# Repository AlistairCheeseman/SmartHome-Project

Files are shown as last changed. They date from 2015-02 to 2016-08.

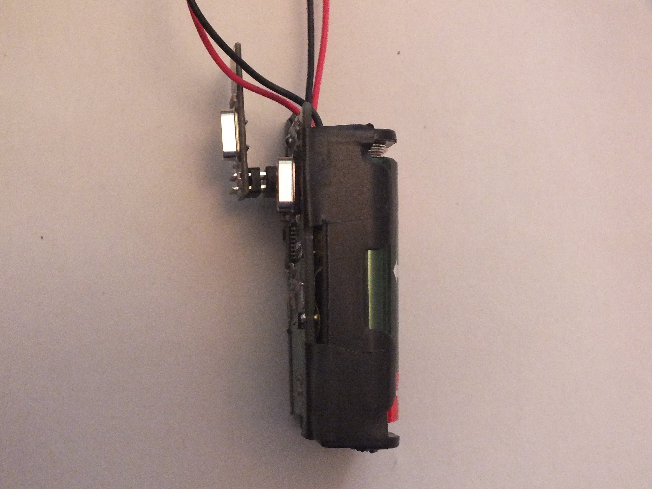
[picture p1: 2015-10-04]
Hardware/Device Pictures/DSCF8864.JPG

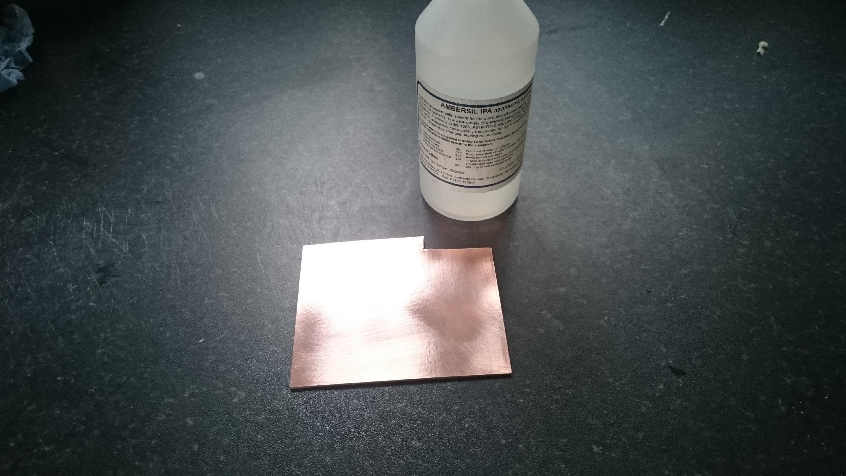
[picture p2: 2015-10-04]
Hardware/Manufacturing Pictures/DSC_0125.JPG

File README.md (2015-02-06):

SmartHome-Project
=================

Final Year degree project to create a set of devices to create a smart home.

Hardware files are created in eagle with PDFs of finished pcbs labelled with which pcb layer they are. Hardware files are created from scratch and a custom library has been created for components not in the default eagle library.

Software has three sections.

	-	www
		copy this to the production web server. the files are based on php 5.6 HTML 5, using ajax and highcharts charting components (http://www.highcharts.com/ - free for non commercial uses).
		
	-	LFS
		This contains a set of manually written build scripts (toolchain and Filesystem) and pre-writted configuration files. After both files (install-*.sh) have been executed on a linux machine there will be a working Linux filesystem. Be sure to change configuration file (buildscript.sh) variables to suit your setup!

	-	Apps
		This contains source for all custom written applications on the server.

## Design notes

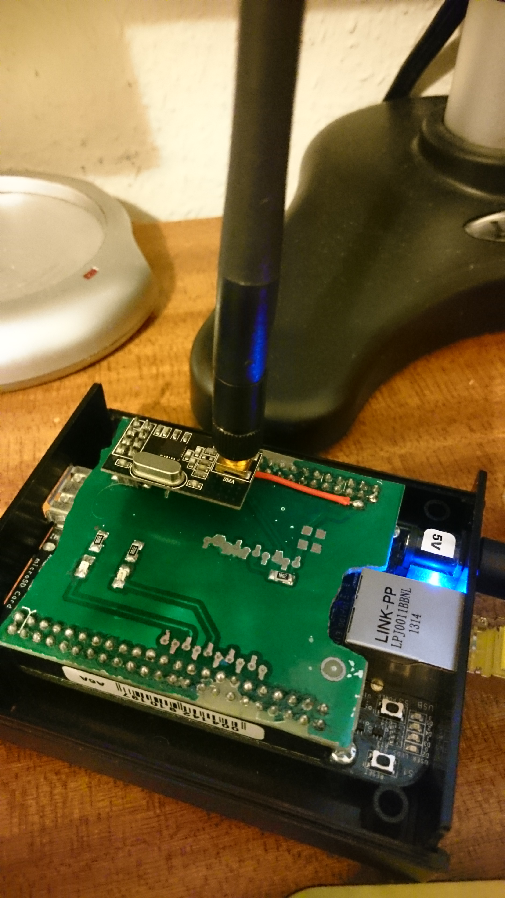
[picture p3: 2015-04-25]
Hardware/BeagleboneCape/BeagleboneCapeV2.JPG

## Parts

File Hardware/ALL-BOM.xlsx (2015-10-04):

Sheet: Power Outlet-BOM
Qty | Value | Device | Package | Parts | Description | OrderNo (Rapid/Mouser) | Cost (Ea) | Cost
1 |  | L-EUL3225P | L3225P | L1 | INDUCTOR, European symbol | 81-LQH32PN220MN0L | 0.29 | £0.29
1 | 0.1u/275V | C-EU050-030X075 | C050-030X075 | C2 | CAPACITOR, European symbol | 80-R46KI3100JHM1M | 0.28 | £0.28
1 | 10k | R-EU_R1206W | R1206W | R2 | RESISTOR, European symbol | 71-CRCW1206J-10K-E3 | 0.05 | £0.05
4 | 120R | R-EU_R1206W | R1206W | R5, R6, R7, R8 | RESISTOR, European symbol | 71-CRCW1206120RJNEB | 0.05 | £0.20
1 | 47u | CPOL-EUE2,5-6E | E2,5-6E | C1 | POLARIZED CAPACITOR, European symbol | 140-REA470M1CBK0511P | 0.04 | £0.04
1 | 8MHz | CRYSTALHC49S | HC49/S | Q1 | CRYSTAL | 774-ATS080B | 0.26 | £0.26
1 | 0.1u | C-EUC1206K | C1206K | C5 | CAPACITOR, European symbol | 77-VJ1206Y104KXJPBC | 0.03 | £0.03
2 | 22p | C-EUC1206K | C1206K | C3, C4 | CAPACITOR, European symbol | 77-VJ1206A220KXACBC | 0.04 | £0.08
1 | 230V 70mA | FUSESH22,5A | SH22,5A | F1 | Fuse | 26-0165 | 0.11 | £0.11
2 | 3k3 | R-EU_R1206W | R1206W | R3, R4 | RESISTOR, European symbol | 71-CRCW12063K30JNEB | 0.05 | £0.10
1 | ATMega 328p-pu | DIL28-3 | DIL28-3 | IC1 | Dual In Line | 556-ATMEGA328P-PU | 2.61 | £2.61
1 | Comms | FE12W | FE12W | SV1 | FEMALE HEADER | 22-5128 | 0.4 | £0.40
1 | EARTH | W237-103 | W237-103 | X7 | WAGO SCREW CLAMP | 21-4012 | 0.2 | £0.20
2 | G5LE | G5LE | G5LE | K1, K2 | RELAY | 653-G5LE-1-ASIDC3 | 0.76 | £1.52
2 | LTV816S | LTV816S | SMD4 | OK1, OK2 | OPTO COUPLER | 859-LTV-816S | 0.13 | £0.26
2 |  | 40-XX | B3F-40XX | S1, S2 | OMRON SWITCH | 78-0286 | 0.35 | £0.70
2 |  | LED5MM | LED5MM | LED1, LED2 | LED | 55-0864 | 0.06 | £0.12
1 | P594 | P594 | P594 | R1 | VARISTOR | 652-MOV-07D361K | 0.07 | £0.07
1 | ULN2003AD | ULN2003AD | SO16 | IC2 | DRIVER ARRAY | 82-5036 | 0.31 | £0.31
3 |  | W237-102 | W237-102 | X1, X2, X3 | WAGO SCREW CLAMP | 21-4011 | 0.12 | £0.36
1 | VTX-214-001-103 | VTX-214-001-103 | VTX214001103 | U$1 |  | 84-2685 | 3.55 | £3.55
 |  |  |  |  |  |  | Total | £11.54

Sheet: Beaglebone Cape
Qty | Value | Device | Package | Parts | Description | OrderNo (Rapid/Mouser) | Cost (Ea) | Cost
1 | 1u | C-EU025-025X050 | C025-025X050 | C1 | CAPACITOR, European symbol | 77-VJ1206Y104KXJPBC | 0.03 | £0.03
2 | HEADER1 | PINHD-2X24 | 2X23 | P8, P9 | PIN HEADER | 54-5042 | 0.46 | £0.92
1 | NRF1 | PINHD-2X4 | 2X04 | NRF24L01 | PIN HEADER | N/A | 0.05 | £0.05
 |  |  |  |  |  |  | Total | £1.00

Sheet: nrf24L01
Qty | Value | Device | Package | Parts | Description | OrderNo (Rapid/Mouser) | Cost (Ea) | Cost
1 | 0.1u | C-EUC1206K | C1206K | C1 | CAPACITOR, European symbol | 77-VJ1206Y104KXJPBC | 0.03 | £0.03
3 | 0R | R-EU_R1206 | R1206 | R3, R4, R6 | RESISTOR, European symbol | 71-CRCW1206-0-E3 | 0.05 | £0.15
2 | 10K | R-EU_R1206 | R1206 | R1, R2 | RESISTOR, European symbol | 71-CRCW1206J-10K-E3 | 0.05 | £0.10
1 | 2X4SMDHEADER | 2X4SMDHEADER | TSM-110-XX-XXX-DV | NRF24L01 |  | N/A | 0.05 | £0.05
1 | BR25S640FJ-WE2 | BR25S640FJ-WE2 | SO8 | EEPROM |  | 51-6386 | 0.73 | £0.73
1 | CON1 | MA09-1W | MA09-1W | SV2 | PIN HEADER | 22-0515 | 0.08 | £0.08
 |  |  |  |  |  |  | Total | £1.14

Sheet: Heating Controller
Qty | Value | Device | Package | Parts | Description | OrderNo (Rapid/Mouser) | Cost (Ea) | Cost
3 |  | L-EUL3230M | L3230M | L1, L2, L3 | INDUCTOR, European symbol | 81-LQH32PN220MN0L | 0.29 | £0.87
4 | 120R | R-EU_R1206 | R1206 | R5, R6, R7, R8 | RESISTOR, European symbol | 71-CRCW1206120RJNEB | 0.05 | £0.20
1 | 0.1u/275V | C15/5 | C15B5 | C2 | CAPACITOR | 80-R46KI3100JHM1M | 0.28 | £0.28
1 | 10k | R-EU_R1206 | R1206 | R2 | RESISTOR, European symbol | 71-CRCW1206J-10K-E3 | 0.05 | £0.05
1 | 16MHz | CRYSTALHC49S | HC49/S | Q1 | CRYSTAL | 774-ATS080B | 0.26 | £0.26
1 | 0.1u | C-EUC1206K | C1206K | C5 | CAPACITOR, European symbol | 77-VJ1206Y104KXJPBC | 0.03 | £0.03
2 | 22p | C-EUC1206K | C1206K | C3, C4 | CAPACITOR, European symbol | 77-VJ1206A220KXACBC | 0.04 | £0.08
1 | 230V 70mA | SH22,5A | SH22,5A | F1 | FUSE HOLDER grid 22,5mm, isolated cap OGN0031 8201, Schurter (Buerklin) | 26-0165 | 0.11 | £0.11
2 | 3k3 | R-EU_R1206 | R1206 | R3, R4 | RESISTOR, European symbol | 71-CRCW12063K30JNEB | 0.05 | £0.10
1 | 47u | CPOL-EUE2.5-7 | E2,5-7 | C1 | POLARIZED CAPACITOR, European symbol | 140-REA470M1CBK0511P | 0.04 | £0.04
1 | ATMega 328p-pu | DIL28-3 | DIL28-3 | IC1 | Dual In Line | 556-ATMEGA328P-PU | 2.61 | £2.61
1 | Comms | FE12W | FE12W | SV1 | FEMALE HEADER | 22-5128 | 0.4 | £0.40
2 | G5LE | G5LE | G5LE | K1, K2 | RELAY | 653-G5LE-1-ASIDC3 | 0.76 | £1.52
2 | HEAT | LED5MM | LED5MM | LED1, LED2 | LED | 55-0864 | 0.06 | £0.12
2 |  | 40-XX | B3F-40XX | S2 | OMRON SWITCH | 78-0286 | 0.35 | £0.70
2 | LTV816S | LTV816S | DIL4-SMD | OK1, OK2 | OPTO COUPLER | 859-LTV-816S | 0.13 | £0.26
4 |  | W237-02P | W237-132 | X1, X2, X3 | WAGO SREW CLAMP | 21-4011 | 0.12 | £0.48
1 | P594 | P594 | P594 | R1 | VARISTOR | 652-MOV-07D361K | 0.07 | £0.07
1 | ULN2003AD | ULN2003AD | SO16 | IC2 | DRIVER ARRAY | 82-5036 | 0.31 | £0.31
1 | VTX-214-001-103 | VTX-214-001-103 | VTX214001103 | U$1 |  | 84-2685 | 3.55 | £3.55
 |  |  |  |  |  |  | Total | £12.04

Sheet: Energy Sensor
Qty | Value | Device | Package | Parts | Description | OrderNo (Rapid/Mouser) | Cost (Ea) | Cost
2 | 10u | C-EUC1206K | C1206K | C1, C10 | CAPACITOR, European symbol | 71-0513 | 0.07 | £0.14
3 | 47u | CPOL-EUE3.5-10 | E3,5-10 | C2 | POLARIZED CAPACITOR, European symbol | 140-REA470M1CBK0511P | 0.04 | £0.12
2 | 1n | C-EU025-025X050 | C025-025X050 | C3, C12 | CAPACITOR, European symbol | 08-0200 | 0.01 | £0.02
1 | 0.1u | C-EUC1206K | C1206K | C5 | CAPACITOR, European symbol | 77-VJ1206Y104KXJPBC | 0.03 | £0.03
1 | 1u | C-EUC1206K | C1206K | C6 | CAPACITOR, European symbol | 77-VJ1206Y104KXJPBC | 0.03 | £0.03
2 | 22p | C-EU025-025X050 | C025-025X050 | C8, C9 | CAPACITOR, European symbol | 08-0046 | 0.01 | £0.02
1 | 1N4148DO35-7 | 1N4148DO35-7 | DO35-7 | D1 | DIODE | 47-3309 | 0.01 | £0.01
1 | 230V 100mA | SH22,5A | SH22,5A | F2 | FUSE HOLDER grid 22,5mm, isolated cap OGN0031 8201, Schurter (Buerklin) | 26-0165 | 0.11 | £0.11
1 | ATMega328p-pu | DIL28-3 | DIL28-3 | IC2 | Dual In Line | 556-ATMEGA328P-PU | 2.61 | £2.61
1 | ld33v | LM317TL | 317TL | IC3 | VOLTAGE REGULATOR | 82-3066 | 0.71 | £0.71
1 | 10u | L-EUL3230M | L3230M | L1 | INDUCTOR, European symbol | 70-ILSB1206ER100K | 0.1 | £0.10
2 | GRN | LED5MM | LED5MM | LINK, ACTIVITY | LED | 55-0864 | 0.06 | £0.12
1 | 16MHz | CRYSTALHC49S | HC49/S | Q1 | CRYSTAL | 774-ATS080B | 0.26 | £0.26
1 | P594 | P594 | P594 | R1 | VARISTOR | 652-MOV-07D361K | 0.07 | £0.07
1 | 22R | R-EU_R1206 | R1206 | R12 | RESISTOR, European symbol | 72-2225 | 0.0028 | £0.0028
4 | 470k | R-EU_0207/7 | 0207/7 | R2, R6, R7, R11 | RESISTOR, European symbol | 62-0437 | 0.0045 | £0.02
1 | 120K | R-EU_0207/7 | 0207/7 | R3 | RESISTOR, European symbol | 62-0420 | 0.006 | £0.01
1 | 10k | R-EU_R1206 | R1206 | R4 | RESISTOR, European symbol | 71-CRCW1206J-10K-E3 | 0.05 | £0.05
2 | 1k | R-EU_0207/7 | 0207/7 | R5, R13 | RESISTOR, European symbol | 62-0370 | 0.006 | £0.01
1 | 10K | R-EU_0207/7 | 0207/7 | R8 | RESISTOR, European symbol | 62-0394 | 0.006 | £0.01
2 | 3k3 | R-EU_0207/7 | 0207/7 | R9, R10 | RESISTOR, European symbol | 62-0382 | 0.006 | £0.01
1 | Comms | FE12W | FE12W | SV1 | FEMALE HEADER | 22-5128 | 0.4 | £0.40
1 | vn20.10 09477 | VV11 | VV11 | TR1 | TRANSFORMER | 88-3574 | 4.1 | £4.10
1 | 3.5MMJACK | 3.5MMJACK | 3.5MMJACK | U$1 |  | 20-0137 | 0.13 | £0.13
1 | MAINS IN | W237-102 | W237-102 | X1 | WAGO SCREW CLAMP | 21-4011 | 0.12 | £0.12
 |  |  |  |  |  |  | Total | £9.21

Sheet: LightSwitch
Qty | Value | Device | Package | Parts | Description | OrderNo (Rapid/Mouser) | Cost (Ea) | Cost
1 | 0.1u | C-EUC1206 | C1206 | C3 | CAPACITOR, European symbol | 77-VJ1206Y104KXJPBC | 0.03 | £0.03
1 | 0.1u 275V | C15/5 | C15B5 | C5 | CAPACITOR | 80-R46KI3100JHM1M | 0.28 | £0.28
1 | 10k | R-EU_R1206 | R1206 | R1 | RESISTOR, European symbol | 71-CRCW1206J-10K-E3 | 0.05 | £0.05
1 | 1u | C-EUC1206K | C1206K | C1 | CAPACITOR, European symbol | 77-VJ1206Y104KXJPBC | 0.03 | £0.03
2 | 22p | C-EUC1206 | C1206 | C6, C7 | CAPACITOR, European symbol | 77-VJ1206A220KXACBC | 0.04 | £0.08
1 | 2X4SMDHEADER | 2X4SMDHEADER | TSM-110-XX-XXX-DV | U$1 |  | N/A | 0.05 | £0.05
1 | 3k3 | R-EU_R1206 | R1206 | R3 | RESISTOR, European symbol | 71-CRCW12063K30JNEB | 0.05 | £0.05
1 | 47u | CPOL-EUE2,5-6E | E2,5-6E | C4 | POLARIZED CAPACITOR, European symbol | 140-REA470M1CBK0511P | 0.04 | £0.04
1 | 70mA | FUSESH22,5A | SH22,5A | F1 | Fuse | 26-0165 | 0.11 | £0.11
1 | 8MHz | CRYSTALHC49U70 | HC49U70 | Q1 | CRYSTAL | 774-ATS080B | 0.26 | £0.26
1 | ATMEGA328P | DIL28-3 | DIL28-3 | IC1 | Dual In Line | 556-ATMEGA328P-PU | 2.61 | £2.61
1 | BEAD | L-EUL3230M | L3230M | L1 | INDUCTOR, European symbol | 81-LQH32PN220MN0L | 0.29 | £0.29
1 | MAINS | W237-102 | W237-102 | X1 | WAGO SCREW CLAMP | 21-4011 | 0.12 | £0.12
1 | P592 | P592 | P592 | R2 | VARISTOR | 652-MOV-07D361K | 0.07 | £0.07
1 | RED | LED5MM | LED5MM | LED1 | LED | 55-0864 | 0.06 | £0.06
1 | SWITCH | 40-XX | B3F-40XX | S1 | OMRON SWITCH | 78-0286 | 0.35 | £0.35
1 | VTX-214-001-103 | VTX-214-001-103 | VTX214001103 | U$2 |  | 84-2685 | 3.55 | £3.55
 |  |  |  |  |  |  | Total | £8.03

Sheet: Environment Sensor
Qty | Value | Device | Package | Parts | Description | OrderNo (Rapid/Mouser) | Cost (Ea) | Cost
1 | 0.1u | C-EUC1206 | C1206 | C4 | CAPACITOR, European symbol | 77-VJ1206Y104KXJPBC | 0.03 | £0.03
3 | 10k | R-EU_R1206 | R1206 | R2, R4, R5 | RESISTOR, European symbol | 71-CRCW1206J-10K-E3 | 0.05 | £0.15
1 | 10u | L-EUL3216C | L3216C | L1 | INDUCTOR, European symbol | 70-ILSB1206ER100K | 0.1 | £0.10
1 | 1u | C-EUC1206K | C1206K | C3 | CAPACITOR, European symbol | 77-VJ1206Y104KXJPBC | 0.03 | £0.03
1 | 1M | R-EU_R1206 | R1206 | R1 | RESISTOR, European symbol | 72-3077 | 0.006 | £0.01
2 | 22p | C-EUC1206K | C1206K | C1, C2 | CAPACITOR, European symbol | 77-VJ1206A220KXACBC | 0.04 | £0.08
1 | 27k | R-EU_R1206 | R1206 | R3 | RESISTOR, European symbol | 62-1819 | 0.007 | £0.01
1 | 2X4SMDHEADER | 2X4SMDHEADER | TSM-110-XX-XXX-DV | U$1 |  | N/A | 0.05 | £0.05
1 | 8MHz | CRYSTALHC49UP | HC49UP | Q1 | CRYSTAL | 774-ATS080B | 0.26 | £0.26
1 | ATMEGA328P-AU | ATMEGA328P-AU | TQFP32-08 | IC1 |  | 556-ATMEGA328P-AU | 2.53 | £2.53
1 | NPDS-9007-020 | NPDS-9007-020 | APDS-9007 | U$2 |  | APDS-9007-020 | 0.69 | £0.69
1 | SI7006A20 | SI7006A20 | 3X3DFN | U$3 |  | 634-SI7006-A20-IM | 2.7 | £2.70
 |  |  |  |  |  |  | Total | £6.63

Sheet: Totals
Main Costs |  | Additional Costs |  | Balance
Device | Cost | Item | Cost | Item | Cost
Power Outlet | £11.54 | NrfRadios | £10.00 | Budget | £140.00
Cape | £1.00 | BeagleBoneBlack | £40.54 | Device Costs | -£49.59
Nrf | £1.14 | Total Cost | £50.54 | Additional Costs | -£50.54
Heating Controller | £12.04 |  |  | Total Available | £39.87
Energy Sensor | £9.21
Lightswitch | £8.03
Environment Sensor | £6.63
Total Cost | £49.59

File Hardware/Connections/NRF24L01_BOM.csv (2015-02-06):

Qty | Value | Device | Package | Parts | Description | MF | MPN | OC_FARNELL | OC_NEWARK
4 | 0R | R-EU_R1206 | R1206 | R3, R4, R5, R6 | RESISTOR, European symbol
2 | 10K | R-EU_R1206 | R1206 | R1, R2 | RESISTOR, European symbol
1 | 2X4SMDHEADER | 2X4SMDHEADER | TSM-110-XX-XXX-DV | U$1
1 | BR25S640FJ-WE2 | BR25S640FJ-WE2 | SO8 | EEPROM
1 | CON1 | MA09-1W | MA09-1W | SV2 | PIN HEADER |  |  | unknown | unknown

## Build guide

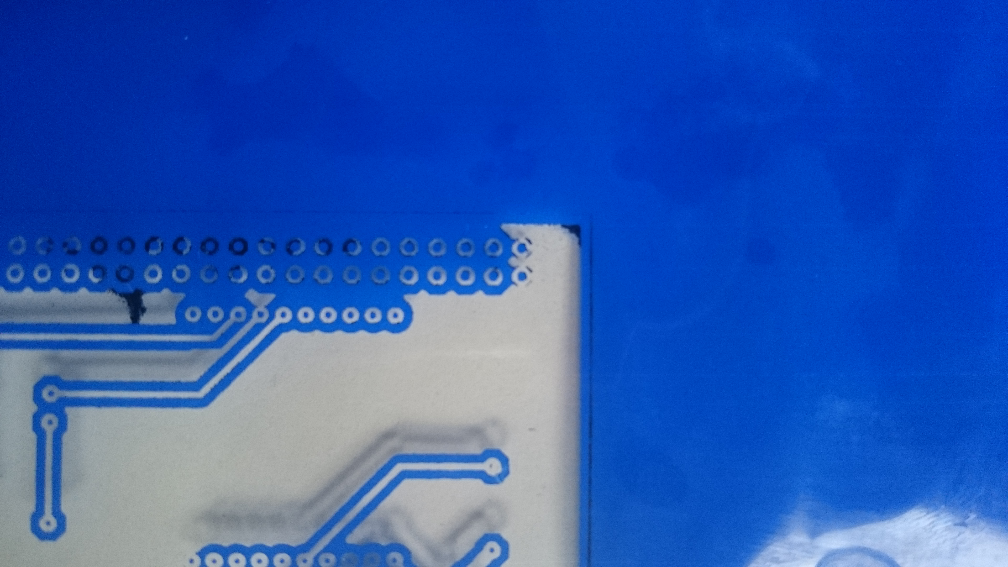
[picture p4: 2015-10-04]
Hardware/Manufacturing Pictures/DSC_0133.JPG

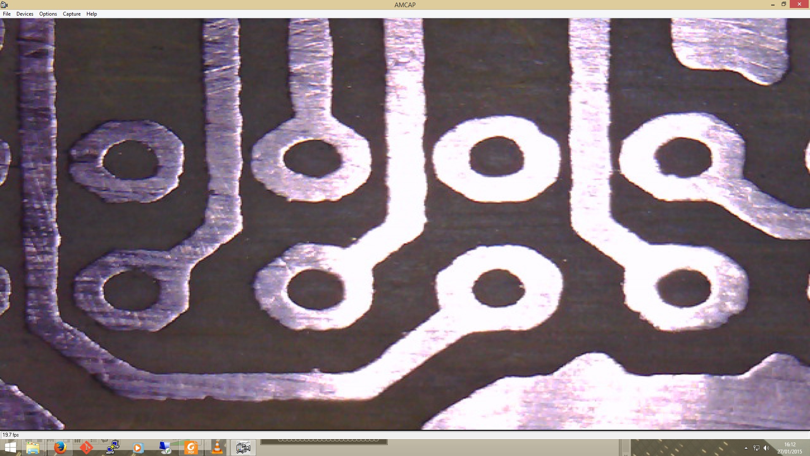
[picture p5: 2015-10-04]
Hardware/Manufacturing Pictures/tracecheck.jpg

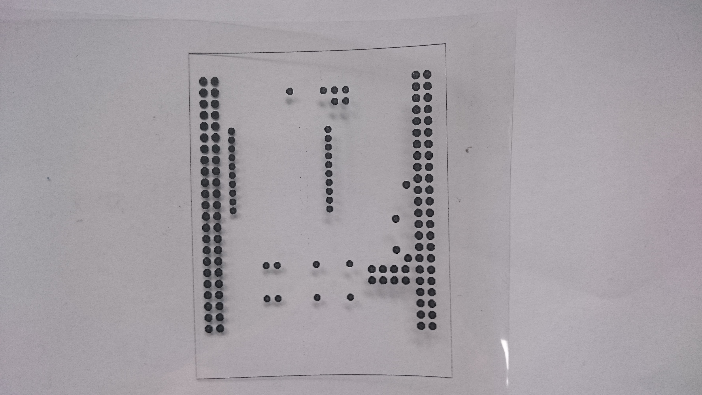
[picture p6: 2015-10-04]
Hardware/Manufacturing Pictures/DSC_0143.JPG

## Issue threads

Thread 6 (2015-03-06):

Increase responsiveness from button press

AlistairCheeseman, 2015-03-06:
currently about 3 seconds between button being pressed and output activating

AlistairCheeseman, 2015-04-08:
node firmware has minimal delays. Presume delays to be caused by the delay on the Wireless-NRF taking too long checking all of the UDP sockets before checking wireless again. Could add active flag to udp port or alternate udp to wireless checking

AlistairCheeseman, 2015-04-09:
massivley improved timing by tweaking how the wireless and udp are checked. Also reduced wait times in wireless-nrf. eacc29497dc60e98685b0f5002f441ee9ac8d552 and 59e4cf4308a73e7380d81faafc5ee5f5404be1e0

AlistairCheeseman, 2015-04-09:
only way to improve response times are to have seperate Rx and Tx radios on the central node. A future enhancement, will not be implemented in this iteration

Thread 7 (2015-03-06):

Wireless performance may be improved by filter cacpacitors close to connector.

AlistairCheeseman, 2015-03-06:
affects NRF comms module and BBB comms Cape.

AlistairCheeseman, 2015-03-11:
commit 3cc00a72c92b5f2744e2d412fb1cf779b57bf025

Closed 2015-03-11.

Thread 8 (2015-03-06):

Update network layer support for broadcast messages

AlistairCheeseman, 2015-03-06:

AlistairCheeseman, 2015-04-08:
Will not be fixed in current development version due to time limitation

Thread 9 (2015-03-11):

NRF24L01 Module unstable on Switch Mode PSU

AlistairCheeseman, 2015-03-11:
Switch Mode power supplies cause unstanbe radio behaviour

AlistairCheeseman, 2015-03-11:
Bypass caps placed close to radio should filter noise. Additionally Inductor on PSU may help

AlistairCheeseman, 2015-03-11:
update design to include bypass caps on nrf24l01 comms board 0.1uF should do.

AlistairCheeseman, 2015-03-11:
High voltage spikes found on supply line. Ferrite bead inductor added to power supply portion removes sikes.

AlistairCheeseman, 2015-03-11:
Beagle bone Shield not to be updated due to working functionally however if given time shield will be redesigned with no xbee and filter cap. to keep costs down.

AlistairCheeseman, 2015-03-11:
added bypass capacitor (filter cap) in commit #3cc00a72 3cc00a72c92b5f2744e2d412fb1cf779b57bf025

AlistairCheeseman, 2015-03-11:
BB Cape updated in new Rev B 4fb89fedb4a7be42ba7f262570636c877007fc2b

Closed 2015-03-11.

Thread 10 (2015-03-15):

LEM Current sensor draws 100mA above datasheet specs.

AlistairCheeseman, 2015-03-15:
this causes power supply to not be stable, will need to lokk into replacing with current transformer or some other alternative.

AlistairCheeseman, 2015-03-15:
will move to sct013 in Rev B

Closed 2015-03-15.

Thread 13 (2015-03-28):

get sensor type, so the correct graph can be plotted and the data processed correctly.

AlistairCheeseman, 2015-03-28:
in functions.js

AlistairCheeseman, 2015-03-31:
fixed in f4725f41ac708df0860dd010b681388ccea5c39f

Closed 2015-03-31.

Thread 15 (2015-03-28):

Need to create listing of all active output devices for home page.

AlistairCheeseman, 2015-03-28:
must be implemented in get_data.php, functions.js and the index page

AlistairCheeseman, 2015-04-08:
fixed in 991fb327bfb3179527417f2b6ef12eb5887684ff and eed3e68e5eb150d30ba15fe0849f0791f031a7eb

Closed 2015-04-08.

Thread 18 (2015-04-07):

implement look up table for Ambient Light Sensor

AlistairCheeseman, 2015-04-07:
current value is sent plain, but should be translated to actual value

AlistairCheeseman, 2015-04-08:
changed from lookup table to 5 distinct regions on linearity. to save the calculations of the look up table as the datasheet contains vague information. It additionally would require calibrated sensors to get said information. Applied in b3624cd42b7b6998f364aa91d808ce02714bea2a

Closed 2015-04-08.

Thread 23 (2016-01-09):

CSN_RADIO P9.25 - prevents use of HDMI audio

AlistairCheeseman, 2016-01-09:
consider relocating this pin to allow for HDMI use

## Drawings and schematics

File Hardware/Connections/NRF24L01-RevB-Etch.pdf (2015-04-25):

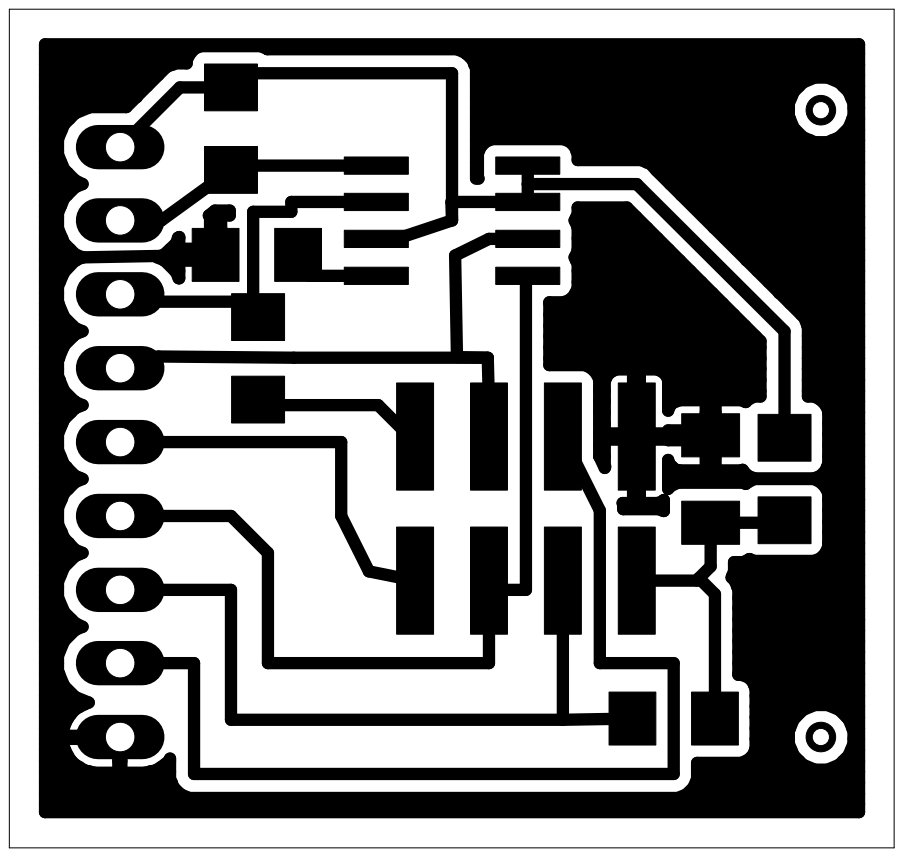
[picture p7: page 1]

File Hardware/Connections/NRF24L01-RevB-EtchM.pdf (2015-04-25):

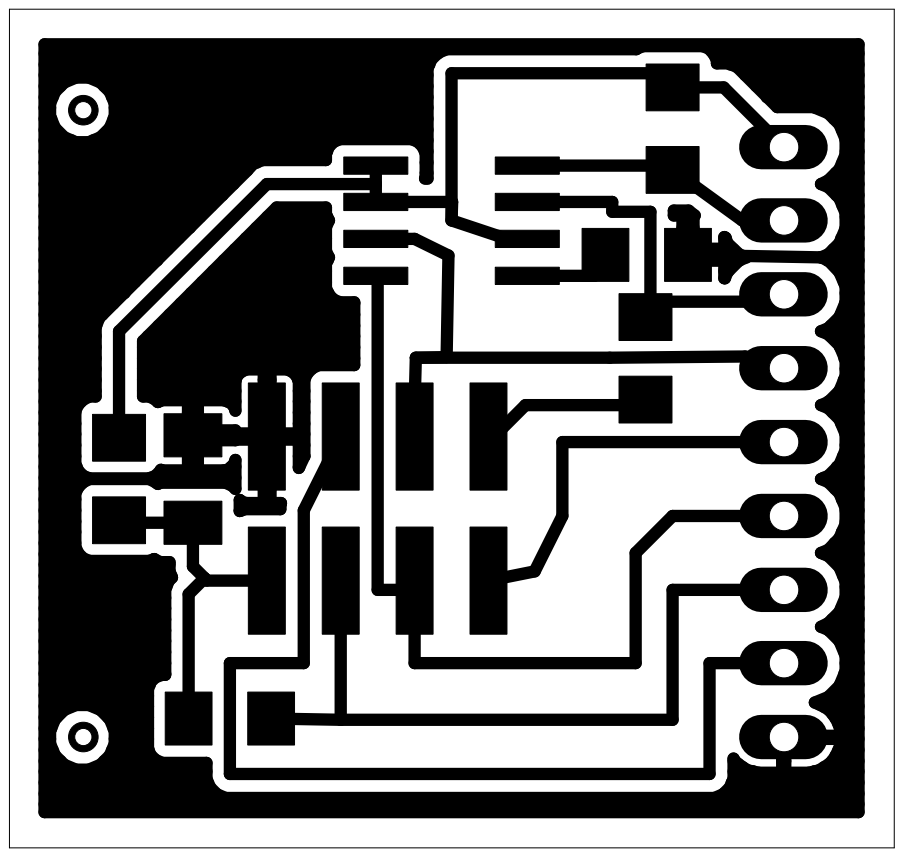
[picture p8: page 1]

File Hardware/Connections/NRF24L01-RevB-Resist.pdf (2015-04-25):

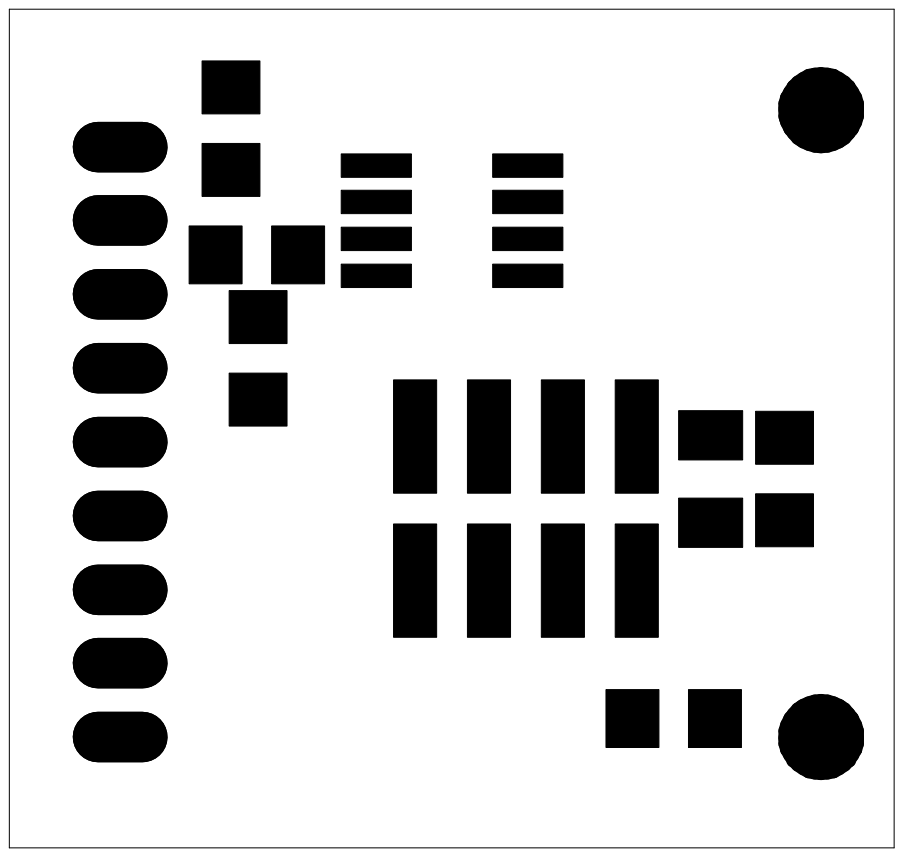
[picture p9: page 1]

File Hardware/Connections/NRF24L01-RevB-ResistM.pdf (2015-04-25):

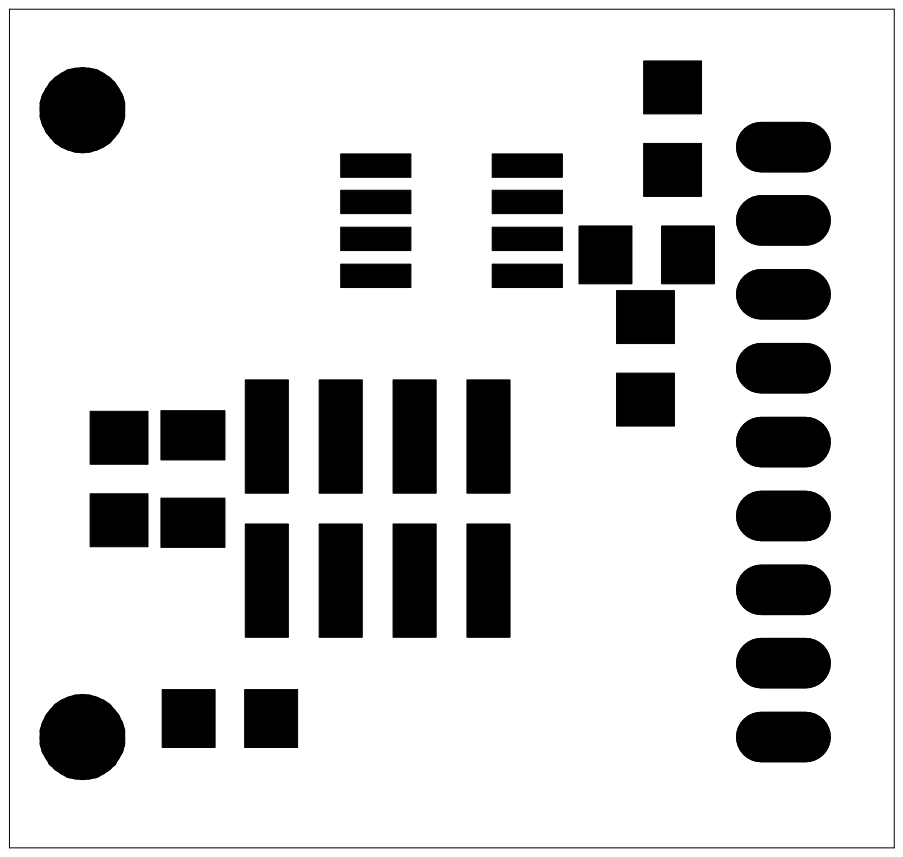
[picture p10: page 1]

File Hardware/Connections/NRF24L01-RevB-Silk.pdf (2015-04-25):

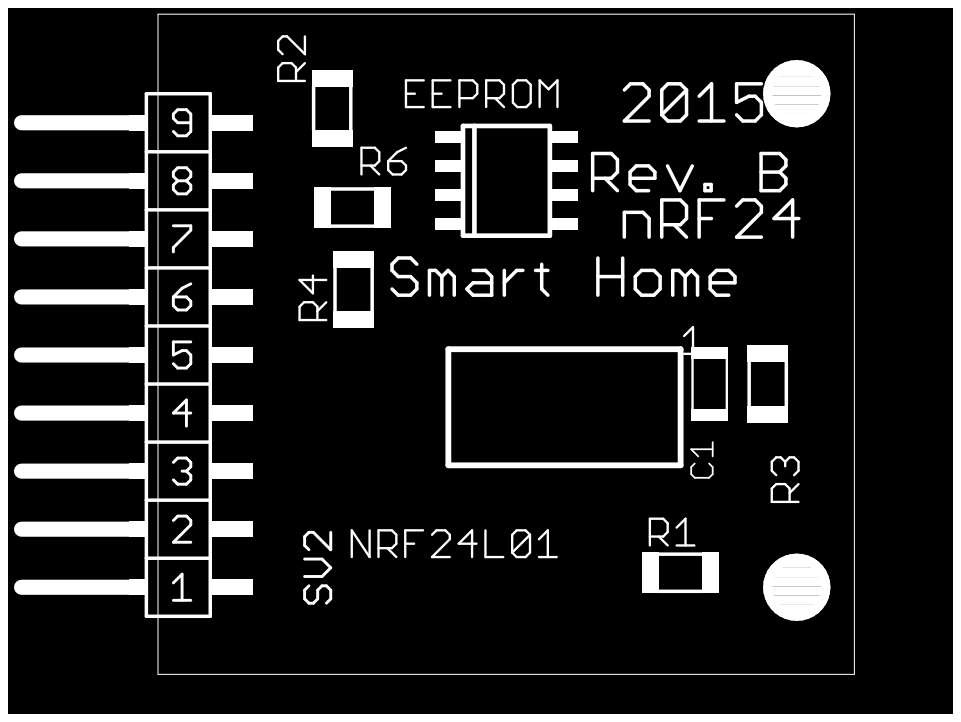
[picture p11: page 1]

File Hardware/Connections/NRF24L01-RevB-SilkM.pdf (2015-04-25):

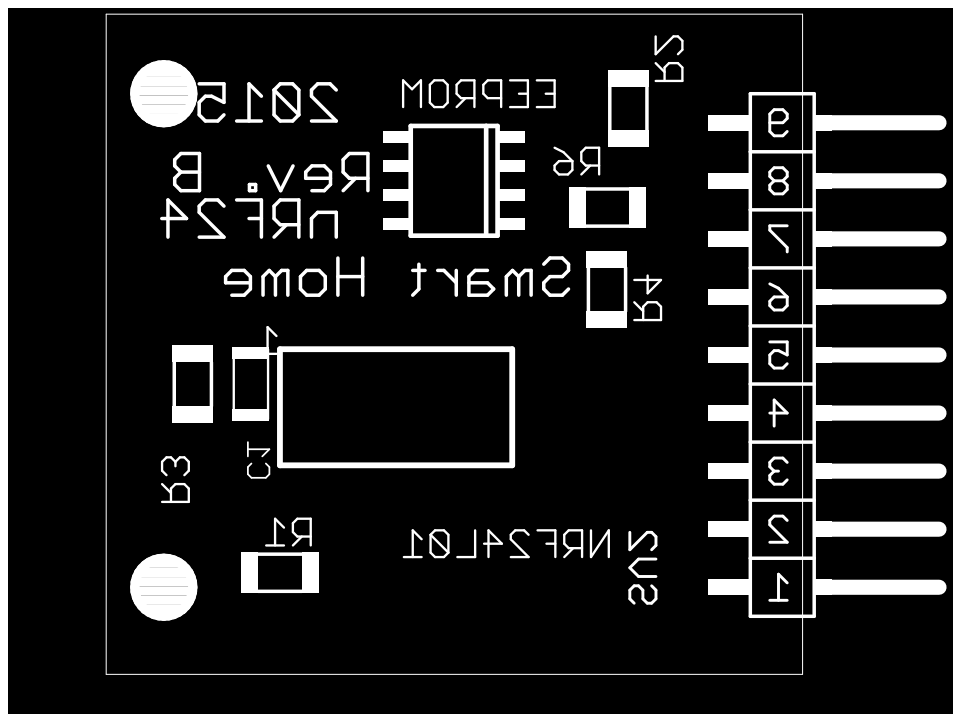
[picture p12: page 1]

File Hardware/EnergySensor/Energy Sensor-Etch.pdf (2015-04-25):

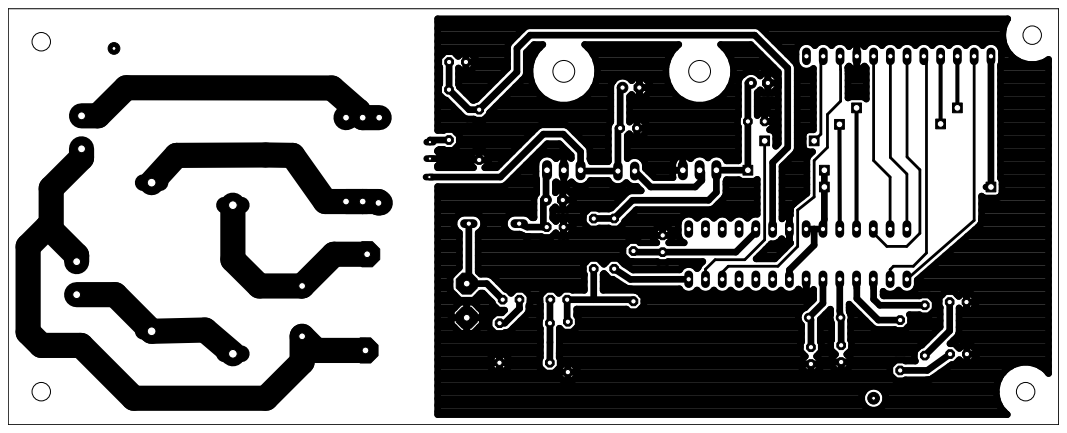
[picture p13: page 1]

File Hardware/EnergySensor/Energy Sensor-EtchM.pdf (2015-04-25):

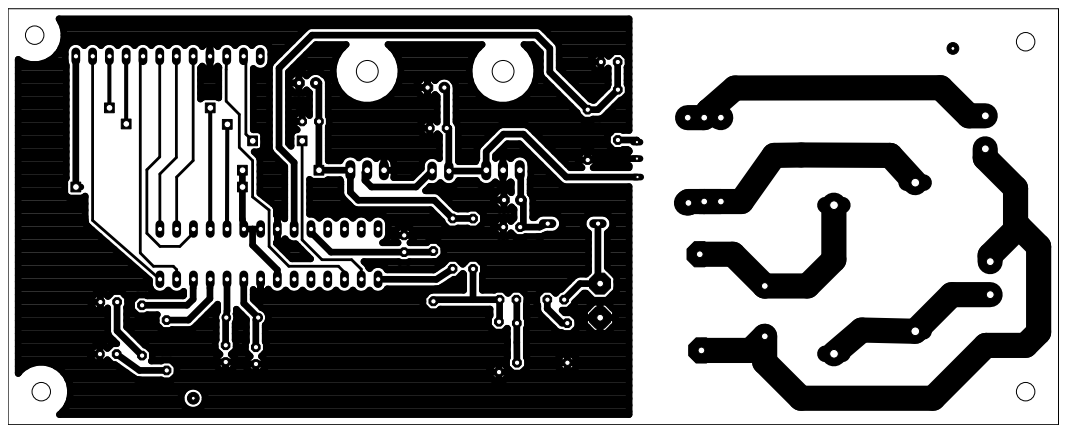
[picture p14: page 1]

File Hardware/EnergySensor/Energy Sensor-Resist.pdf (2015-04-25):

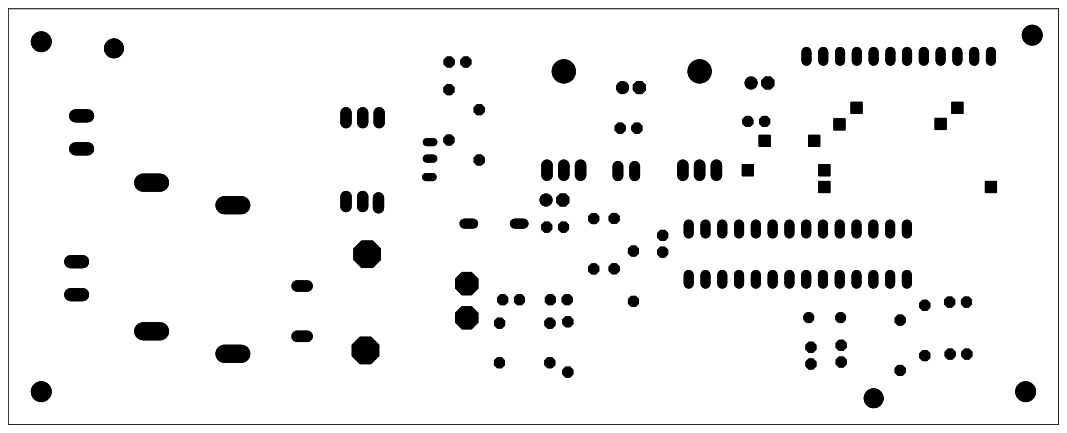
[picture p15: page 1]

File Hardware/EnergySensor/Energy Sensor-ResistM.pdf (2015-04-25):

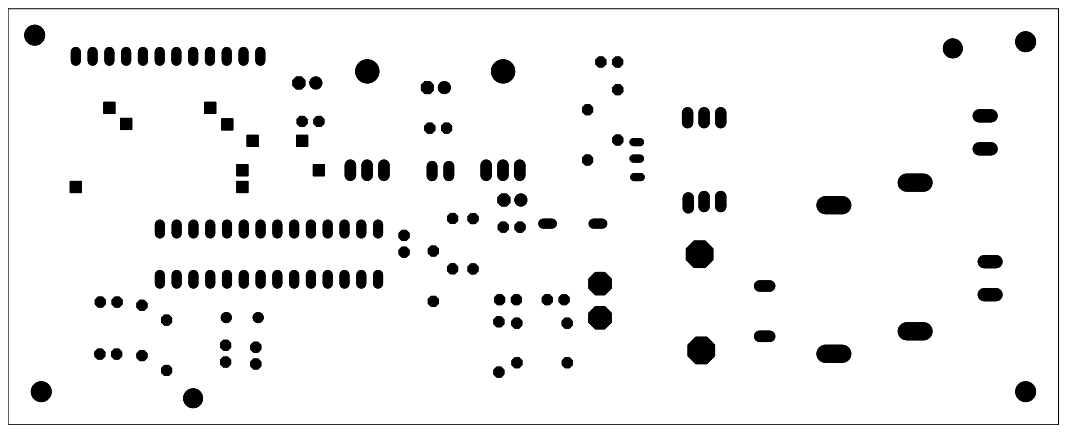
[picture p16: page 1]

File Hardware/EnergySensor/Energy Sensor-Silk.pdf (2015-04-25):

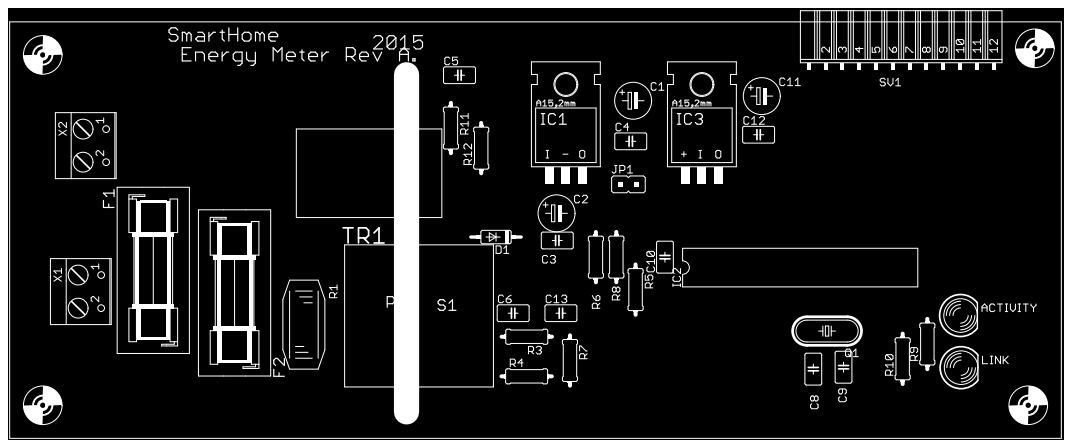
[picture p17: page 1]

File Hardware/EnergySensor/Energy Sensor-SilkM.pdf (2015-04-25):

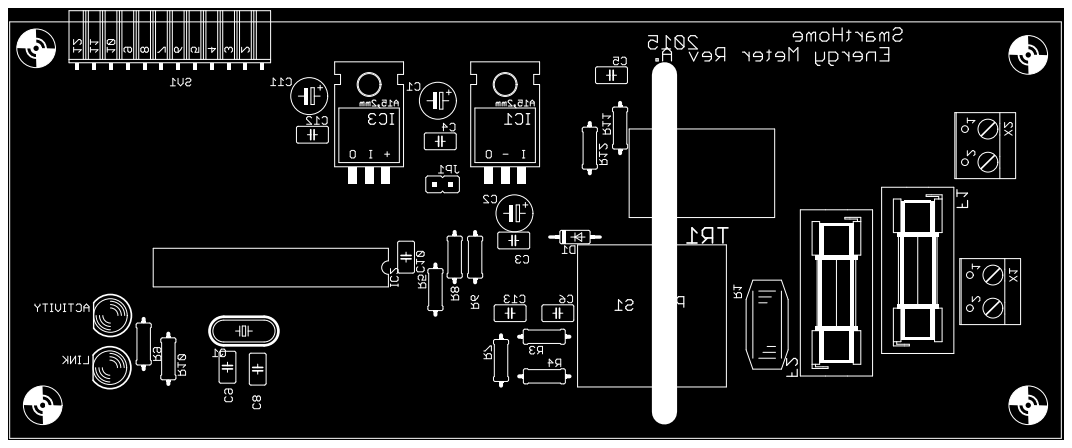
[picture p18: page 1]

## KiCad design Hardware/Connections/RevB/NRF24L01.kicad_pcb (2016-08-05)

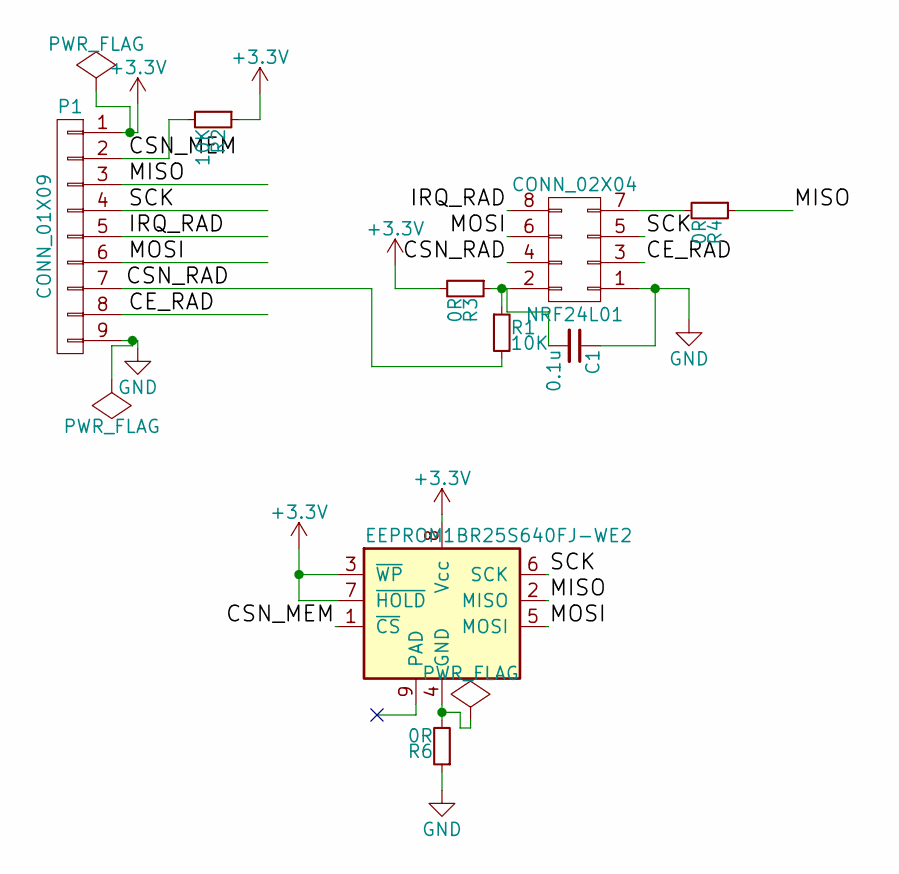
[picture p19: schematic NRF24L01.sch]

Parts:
C1: 0.1u; C_1206_HandSoldering
EEPROM1: BR25S640FJ-WE2; SOP8
NRF24L01: CONN_02X04; Pin_Header_Straight_2x04SMD
P1: CONN_01X09; Pin_Header_Straight_1x09
R1, R2: 10K; R_1206_HandSoldering
R3, R4, R6: 0R; R_1206_HandSoldering

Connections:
+3V3: EEPROM1.3 (~WP), EEPROM1.7 (~HOLD), EEPROM1.8 (Vcc), P1.1, R2.1, R3.2
/CE_RAD: NRF24L01.3, P1.8
/CSN_MEM: EEPROM1.1 (~CS), P1.2, R2.2
/CSN_RAD: NRF24L01.4, P1.7, R1.2
/IRQ_RAD: NRF24L01.8, P1.5
/MISO: EEPROM1.2 (MISO), P1.3, R4.1
/MOSI: EEPROM1.5 (MOSI), NRF24L01.6, P1.6
/SCK: EEPROM1.6 (SCK), NRF24L01.5, P1.4
GND: C1.1, NRF24L01.1, P1.9, R6.1
unnamed: C1.2, NRF24L01.2, R1.1, R3.1
unnamed: EEPROM1.4 (GND), R6.2
unnamed: NRF24L01.7, R4.2

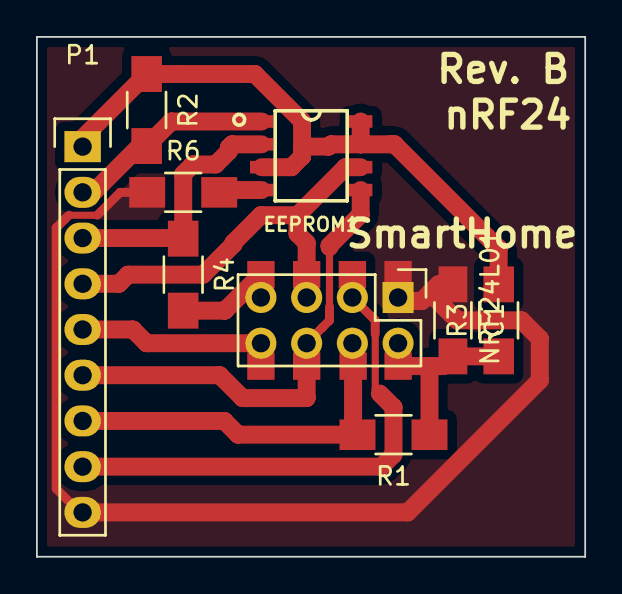
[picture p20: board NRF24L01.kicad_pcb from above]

Board: 2 copper layers, 30.5 x 28.9 mm, 9 parts (0 on the bottom side), 12 nets.

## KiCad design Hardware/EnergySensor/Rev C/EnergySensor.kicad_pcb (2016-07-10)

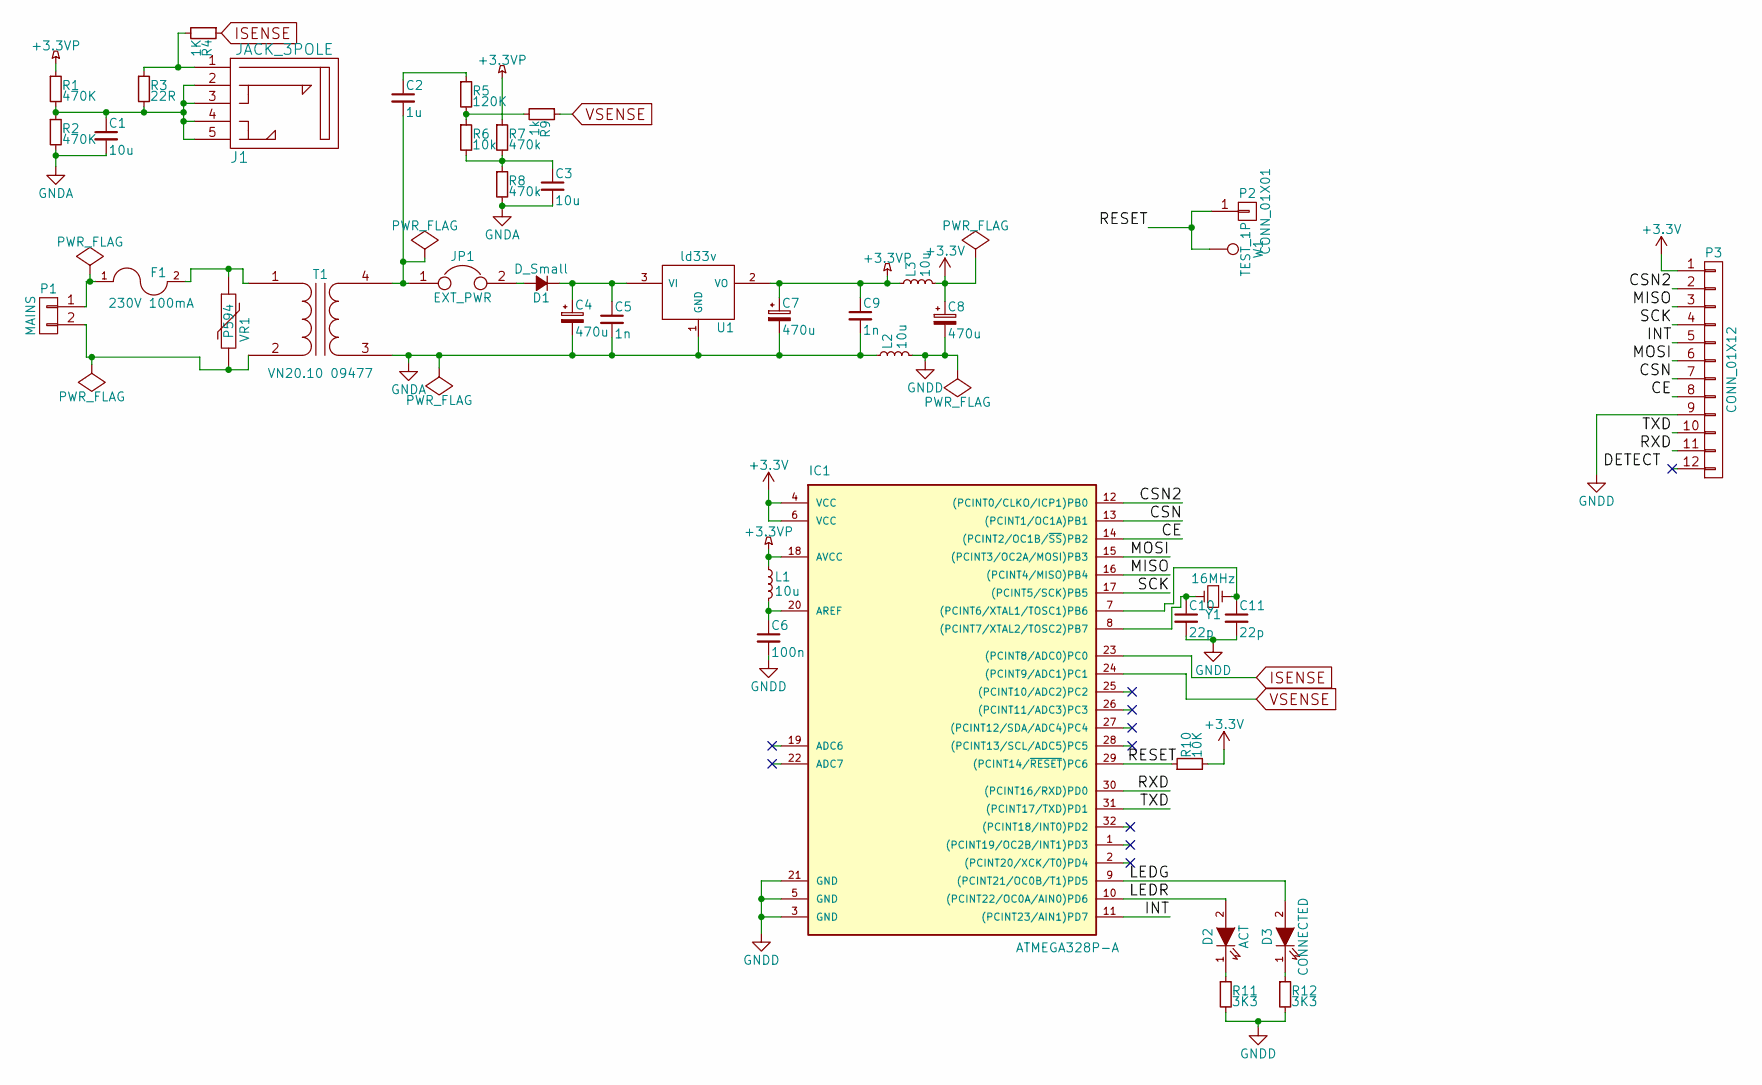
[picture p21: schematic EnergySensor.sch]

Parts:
C1, C3: 10u; C_1206_HandSoldering
C2: 1u; C_1206_HandSoldering
C4, C7, C8: 470u; c_elec_5x4.5
C5, C9: 1n; C_1206_HandSoldering
C6: 100n; C_1206_HandSoldering
C10, C11: 22p; C_1206_HandSoldering
D1: D_Small; MELF-RM10_Universal_Handsoldering
D2: ACT; LED-0805
D3: CONNECTED; LED-0805
F1: 230V 100mA; Fuse_SMD1206_HandSoldering
IC1: ATMEGA328P-A; TQFP-32_7x7mm_Pitch0.8mm
J1: JACK_3POLE
JP1: EXT_PWR; Socket_Strip_Straight_1x02
L1, L2, L3: 10u; Inductor_1212
P1: MAINS; AK300-2
P2: CONN_01X01; Pin_Header_Straight_1x01
P3: CONN_01X12; Socket_Strip_Angled_1x12
R1, R2: 470K; R_1206_HandSoldering
R3: 22R; R_1206_HandSoldering
R4: 1K; R_1206_HandSoldering
R5: 120K; R_1206_HandSoldering
R6: 10k; R_1206_HandSoldering
R7, R8: 470k; R_1206_HandSoldering
R9: 1k; R_1206_HandSoldering
R10: 10K; R_1206_HandSoldering
R11, R12: 3K3; R_1206_HandSoldering
T1: VN20.10 09477; TEZ-22x24
U1: ld33v; TO-220_Neutral123_Vertical
VR1: P594; RV_Disc_D7_W3.4_P5
W1: TEST_1P; Measurement_Point_Round-SMD-Pad_Big
Y1: 16MHz; Crystal_HC49-SD_SMD

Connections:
+3.3VP: C7.1, C9.1, IC1.18 (AVCC), L1.1, L3.1, R1.1, R7.1, U1.2 (VO)
+3V3: C8.1, IC1.4 (VCC), IC1.6 (VCC), L3.2, P3.1, R10.2
/CE: IC1.14 ((PCINT2/OC1B/~SS~)PB2), P3.8
/CSN: IC1.13 ((PCINT1/OC1A)PB1), P3.7
/CSN2: IC1.12 ((PCINT0/CLKO/ICP1)PB0), P3.2
/INT: IC1.11 ((PCINT23/AIN1)PD7), P3.5
/LEDG: D3.2 (A), IC1.9 ((PCINT21/OC0B/T1)PD5)
/LEDR: D2.2 (A), IC1.10 ((PCINT22/OC0A/AIN0)PD6)
/MISO: IC1.16 ((PCINT4/MISO)PB4), P3.3
/MOSI: IC1.15 ((PCINT3/OC2A/MOSI)PB3), P3.6
/RESET: IC1.29 ((PCINT14/~RESET~)PC6), P2.1, R10.1, W1.1
/RXD: IC1.30 ((PCINT16/RXD)PD0), P3.11
/SCK: IC1.17 ((PCINT5/SCK)PB5), P3.4
/TXD: IC1.31 ((PCINT17/TXD)PD1), P3.10
GNDA: C1.2, C3.2, C4.2, C5.2, C7.2, C9.2, L2.1, R2.2, R8.2, T1.3 (SA), U1.1 (GND)
GNDD: C6.2, C8.2, C10.2, C11.2, IC1.3 (GND), IC1.5 (GND), IC1.21 (GND), L2.2, P3.9, R11.2, R12.2
ISENSE: IC1.23 ((PCINT8/ADC0)PC0), R4.1
unnamed: C1.1, J1.2, J1.3, J1.4, J1.5, R1.2, R2.1, R3.2
unnamed: C2.1, R5.1
unnamed: C2.2, JP1.1, T1.4 (SB)
unnamed: C3.1, R6.2, R7.2, R8.1
unnamed: C4.1, C5.1, D1.1 (K), U1.3 (VI)
unnamed: C6.1, IC1.20 (AREF), L1.2
unnamed: C10.1, IC1.8 ((PCINT7/XTAL2/TOSC2)PB7), Y1.2
unnamed: C11.1, IC1.7 ((PCINT6/XTAL1/TOSC1)PB6), Y1.1
unnamed: D1.2 (A), JP1.2
unnamed: D2.1 (K), R11.1
unnamed: D3.1 (K), R12.1
unnamed: F1.1, P1.1
unnamed: F1.2, T1.1 (AA), VR1.1
unnamed: J1.1, R3.1, R4.2
unnamed: P1.2, T1.2 (AB), VR1.2
unnamed: R5.2, R6.1, R9.2
VSENSE: IC1.24 ((PCINT9/ADC1)PC1), R9.1

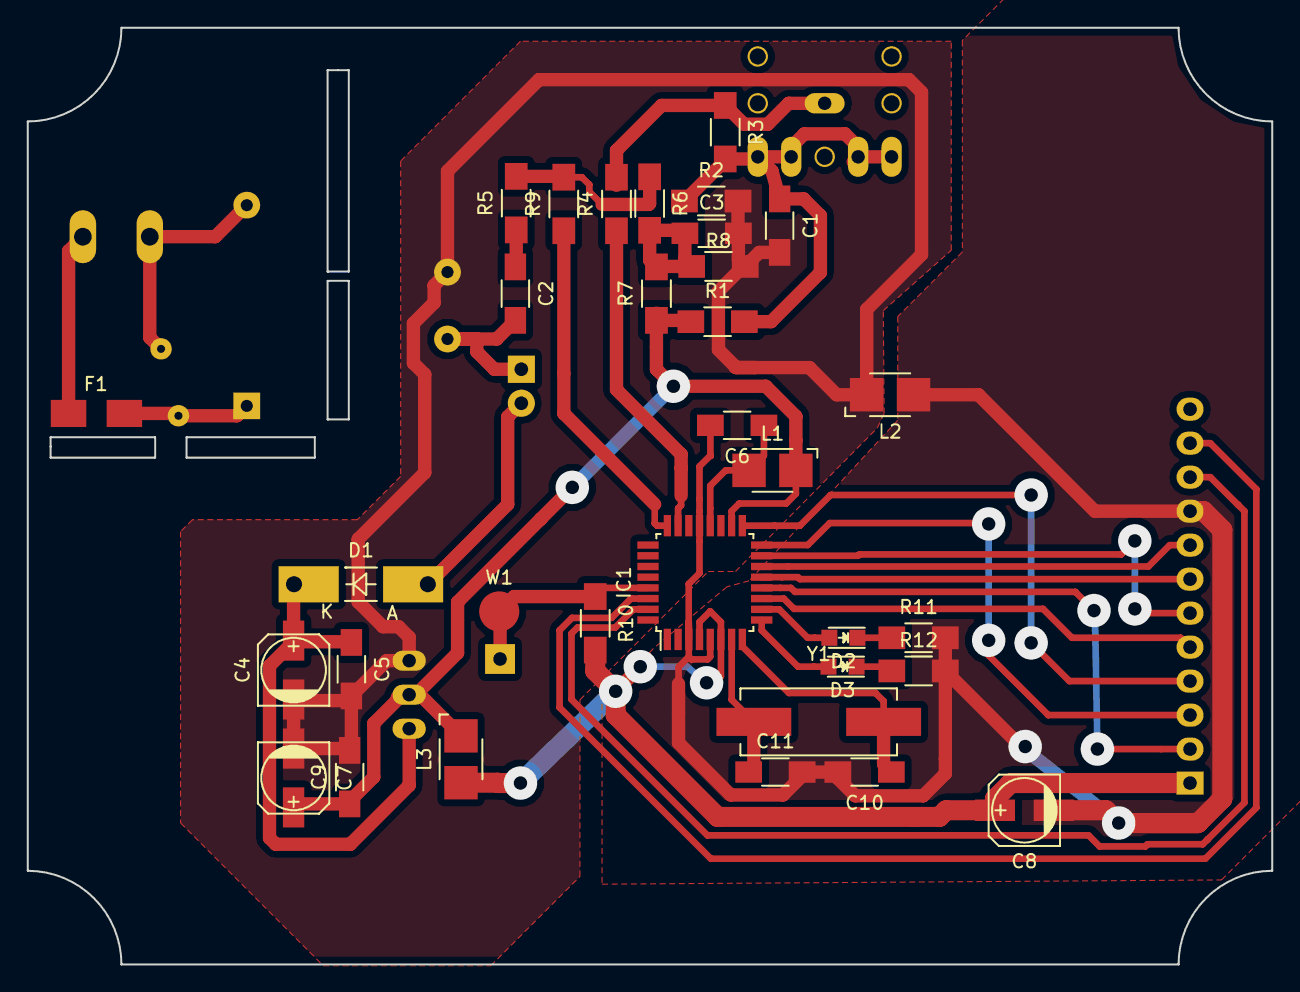
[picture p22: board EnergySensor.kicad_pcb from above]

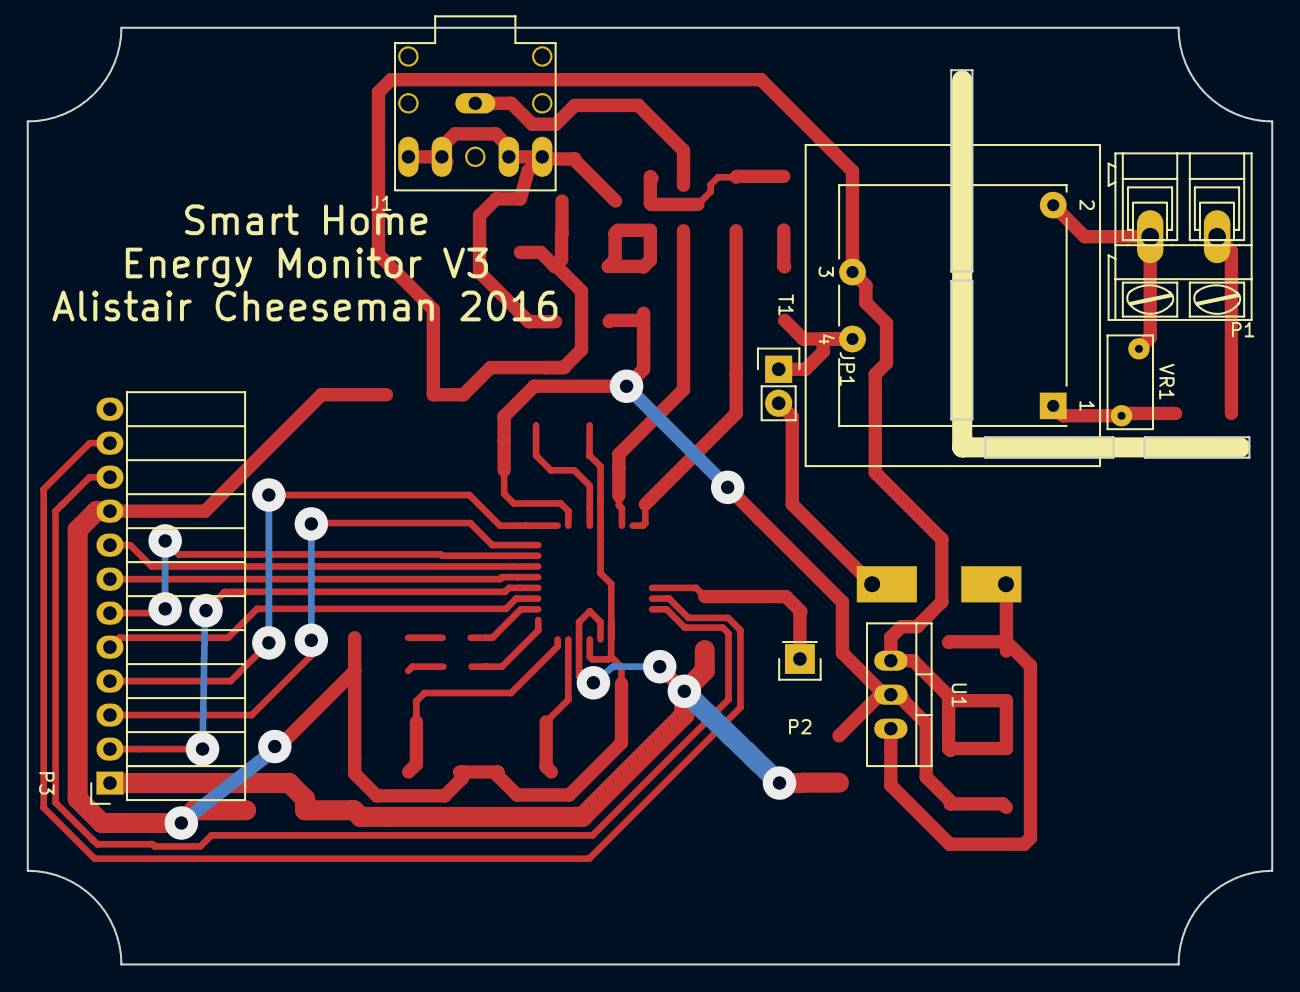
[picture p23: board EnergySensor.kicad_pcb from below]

Board: 2 copper layers, 93.0 x 70.0 mm, 41 parts (8 on the bottom side), 34 nets.

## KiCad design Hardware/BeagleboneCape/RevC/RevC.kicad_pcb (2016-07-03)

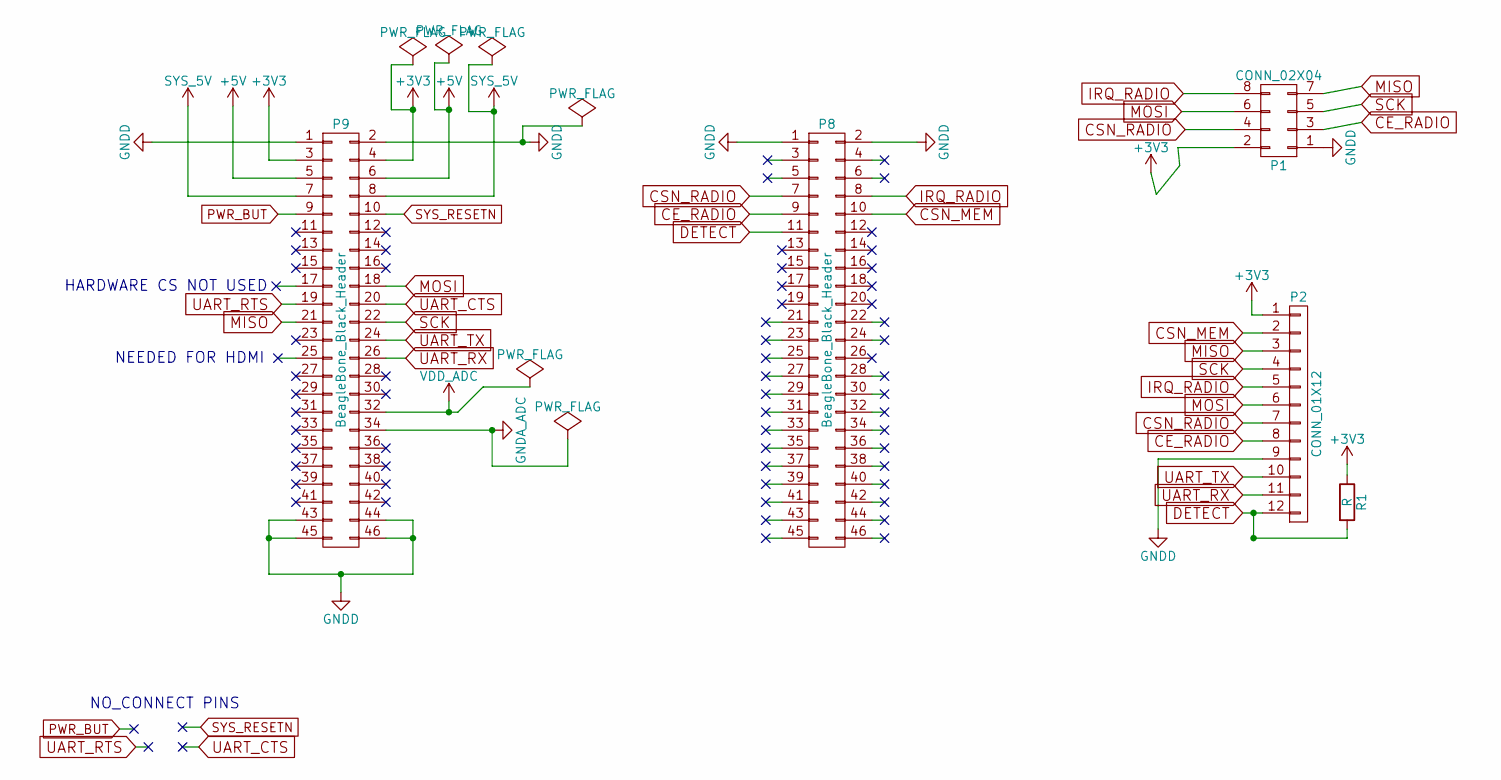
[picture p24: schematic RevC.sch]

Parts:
P1: CONN_02X04; Pin_Header_Straight_2x04
P2: CONN_01X12; Pin_Header_Straight_1x12
P8, P9: BeagleBone_Black_Header; Socket_BeagleBone_Black
R1: R; R_1210_HandSoldering

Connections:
+3V3: P1.2, P2.1, P9.3, P9.4, R1.1
+5V: P9.5, P9.6
CE_RADIO: P1.3, P2.8, P8.9
CSN_MEM: P2.2, P8.10
CSN_RADIO: P1.4, P2.7, P8.7
DETECT: P2.12, P8.11, R1.2
GNDA_ADC: P9.34
GNDD: P1.1, P2.9, P8.1, P8.2, P9.1, P9.2, P9.43, P9.44, P9.45, P9.46
IRQ_RADIO: P1.8, P2.5, P8.8
MISO: P1.7, P2.3, P9.21
MOSI: P1.6, P2.6, P9.18
PWR_BUT: P9.9
SCK: P1.5, P2.4, P9.22
SYS_5V: P9.7, P9.8
SYS_RESETN: P9.10
UART_CTS: P9.20
UART_RTS: P9.19
UART_RX: P2.11, P9.26
UART_TX: P2.10, P9.24
VDD_ADC: P9.32

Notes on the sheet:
NEEDED FOR HDMI
HARDWARE CS NOT USED
NO_CONNECT PINS

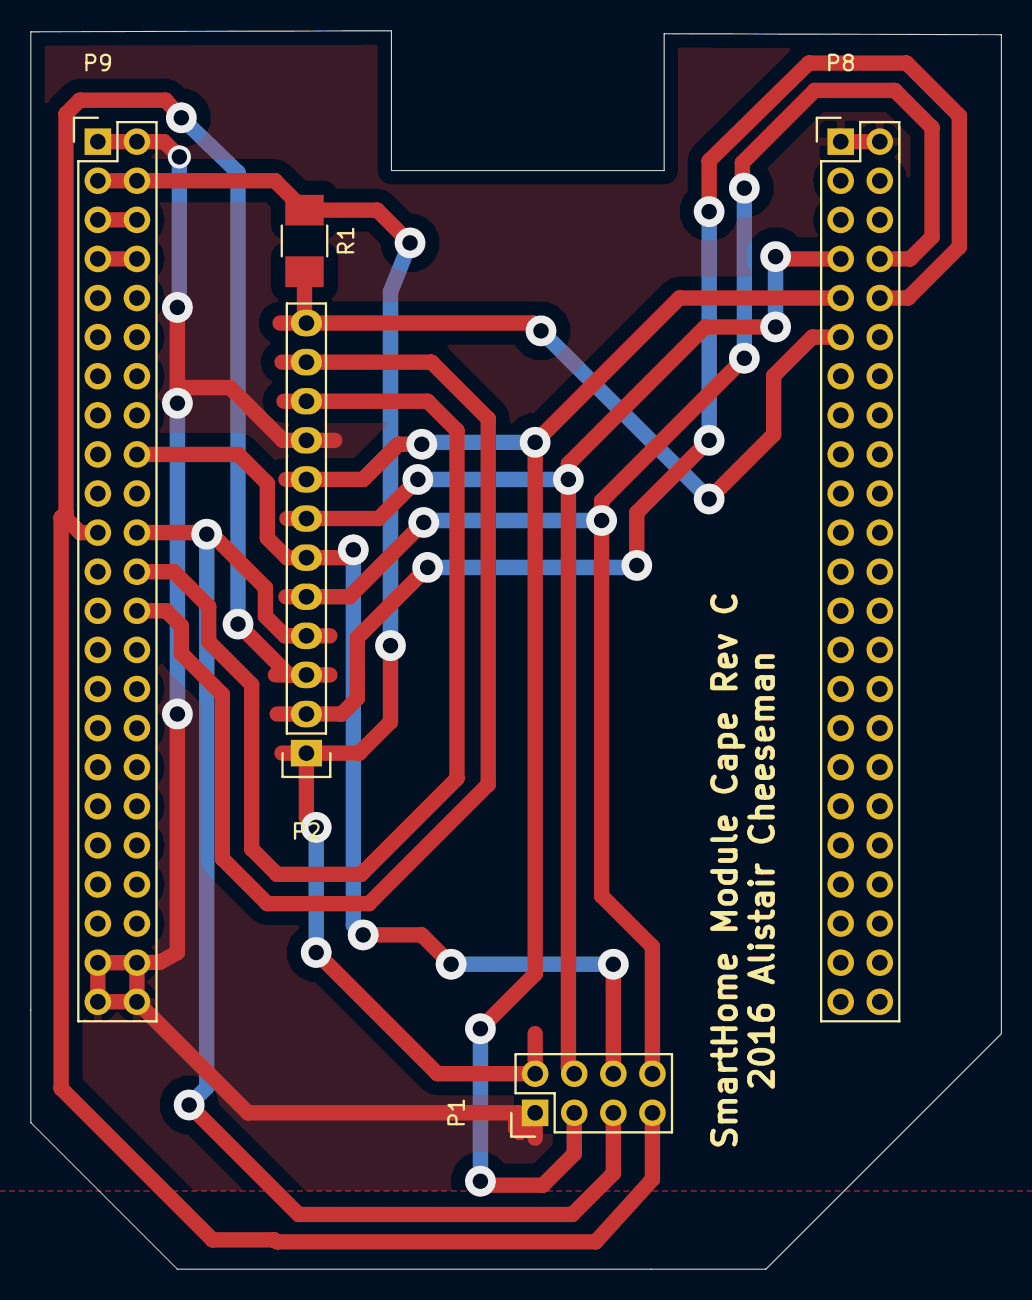
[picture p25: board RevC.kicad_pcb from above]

Board: 2 copper layers, 63.1 x 80.5 mm, 5 parts (0 on the bottom side), 14 nets.

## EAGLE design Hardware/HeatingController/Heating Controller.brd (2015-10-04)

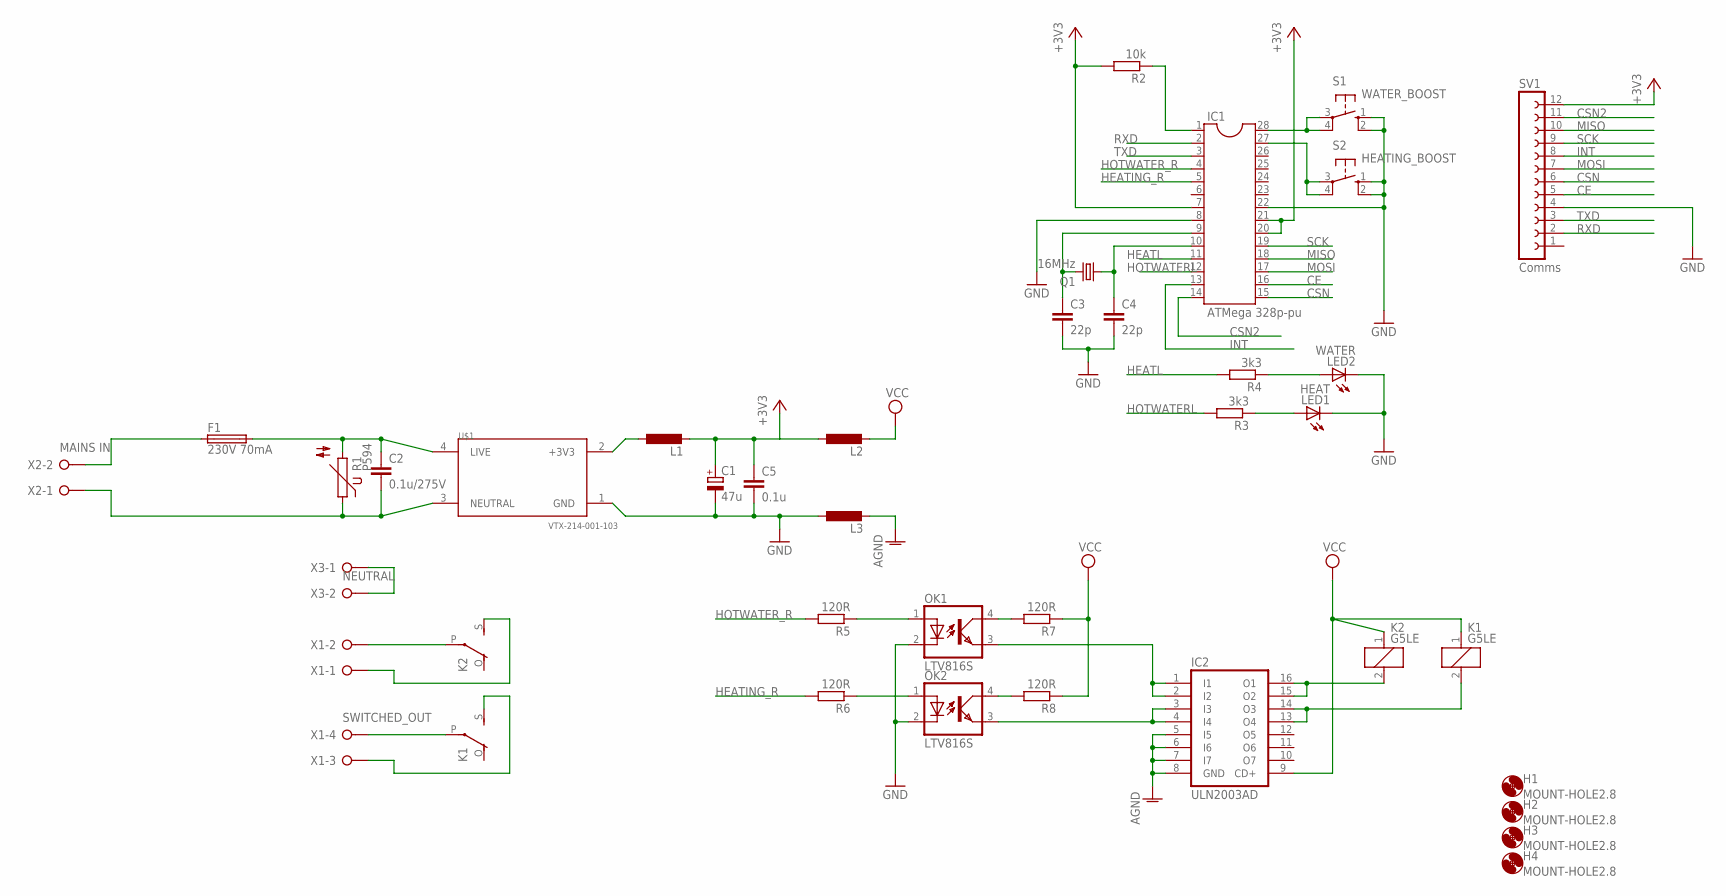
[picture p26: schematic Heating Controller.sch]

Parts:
C1: 47u; E2,5-7
C2: 0.1u/275V; C15B5
C3, C4: 22p; C1206K
C5: 0.1u; C1206K
F1: 230V 70mA; SH22,5A
H1, H2, H3, H4: MOUNT-HOLE2.8; 2,8
IC1: ATMega 328p-pu; DIL28-3
IC2: ULN2003AD; SO16
K1, K2: G5LE
L1, L2, L3: L-EUL3230M; L3230M
LED1: HEAT; LED5MM
LED2: WATER; LED5MM
OK1, OK2: LTV816S; DIL4-SMD
Q1: 16MHz; HC49/S
R1: P594
R2: 10k; R1206
R3, R4: 3k3; R1206
R5, R6, R7, R8: 120R; R1206
S1: WATER_BOOST; B3F-40XX
S2: HEATING_BOOST; B3F-40XX
SV1: Comms; FE12W
U$1: VTX-214-001-103; VTX214001103
X1: SWITCHED_OUT; W237-4P
X2: MAINS IN; W237-132
X3: NEUTRAL; W237-132

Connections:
+3V3: C1.+, C5.1, IC1.7, IC1.20, IC1.21, L1.2, L2.1, R2.2, SV1.12
+3V3A: L1.1, U$1.2 (+3V3)
AGND: IC2.5 (I5), IC2.6 (I6), IC2.7 (I7), IC2.8 (GND), L3.2
CE: IC1.16, SV1.5
CSN: IC1.15, SV1.6
CSN2: IC1.14, SV1.11
GND: C1.-, C3.2, C4.2, C5.2, IC1.8, IC1.22, L3.1, LED1.K (C), LED2.K (C), OK1.2 (C), OK2.2 (C), S1.1 (S), S1.2 (S1), S2.1 (S), S2.2 (S1), SV1.4, U$1.1 (GND)
HEATING_R: IC1.5, R6.2
HEATL: IC1.11, R4.2
HOTWATERL: IC1.12, R3.2
HOTWATER_R: IC1.4, R5.2
INT: IC1.13, SV1.8
MISO: IC1.18, SV1.10
MOSI: IC1.17, SV1.7
unnamed: F1.1, X2.2
unnamed: C2.1, F1.2, R1.2, U$1.4 (LIVE)
unnamed: C2.2, R1.1, U$1.3 (NEUTRAL), X2.1
unnamed: IC1.1, R2.1
unnamed: C3.1, IC1.9, Q1.2
unnamed: C4.1, IC1.10, Q1.1
unnamed: LED1.A, R3.1
unnamed: LED2.A, R4.1
unnamed: IC1.28, S1.3, S1.4 (P1)
unnamed: IC1.27, S2.3, S2.4 (P1)
unnamed: OK1.1 (A), R5.1
unnamed: IC2.15 (O2), IC2.16 (O1), K2.2
unnamed: IC2.13 (O4), IC2.14 (O3), K1.2
unnamed: OK2.1 (A), R6.1
unnamed: K2.P, X1.2
unnamed: K2.S, X1.1
unnamed: K1.P, X1.4
unnamed: K1.S, X1.3
unnamed: X3.1, X3.2
unnamed: OK1.4 (COL), R7.2
unnamed: OK2.4 (COL), R8.2
unnamed: IC2.1 (I1), IC2.2 (I2), OK1.3 (EMIT)
unnamed: IC2.3 (I3), IC2.4 (I4), OK2.3 (EMIT)
RXD: IC1.2, SV1.2
SCK: IC1.19, SV1.9
TXD: IC1.3, SV1.3
VCC: IC2.9 (CD+), K1.1, K2.1, L2.2, R7.1, R8.1

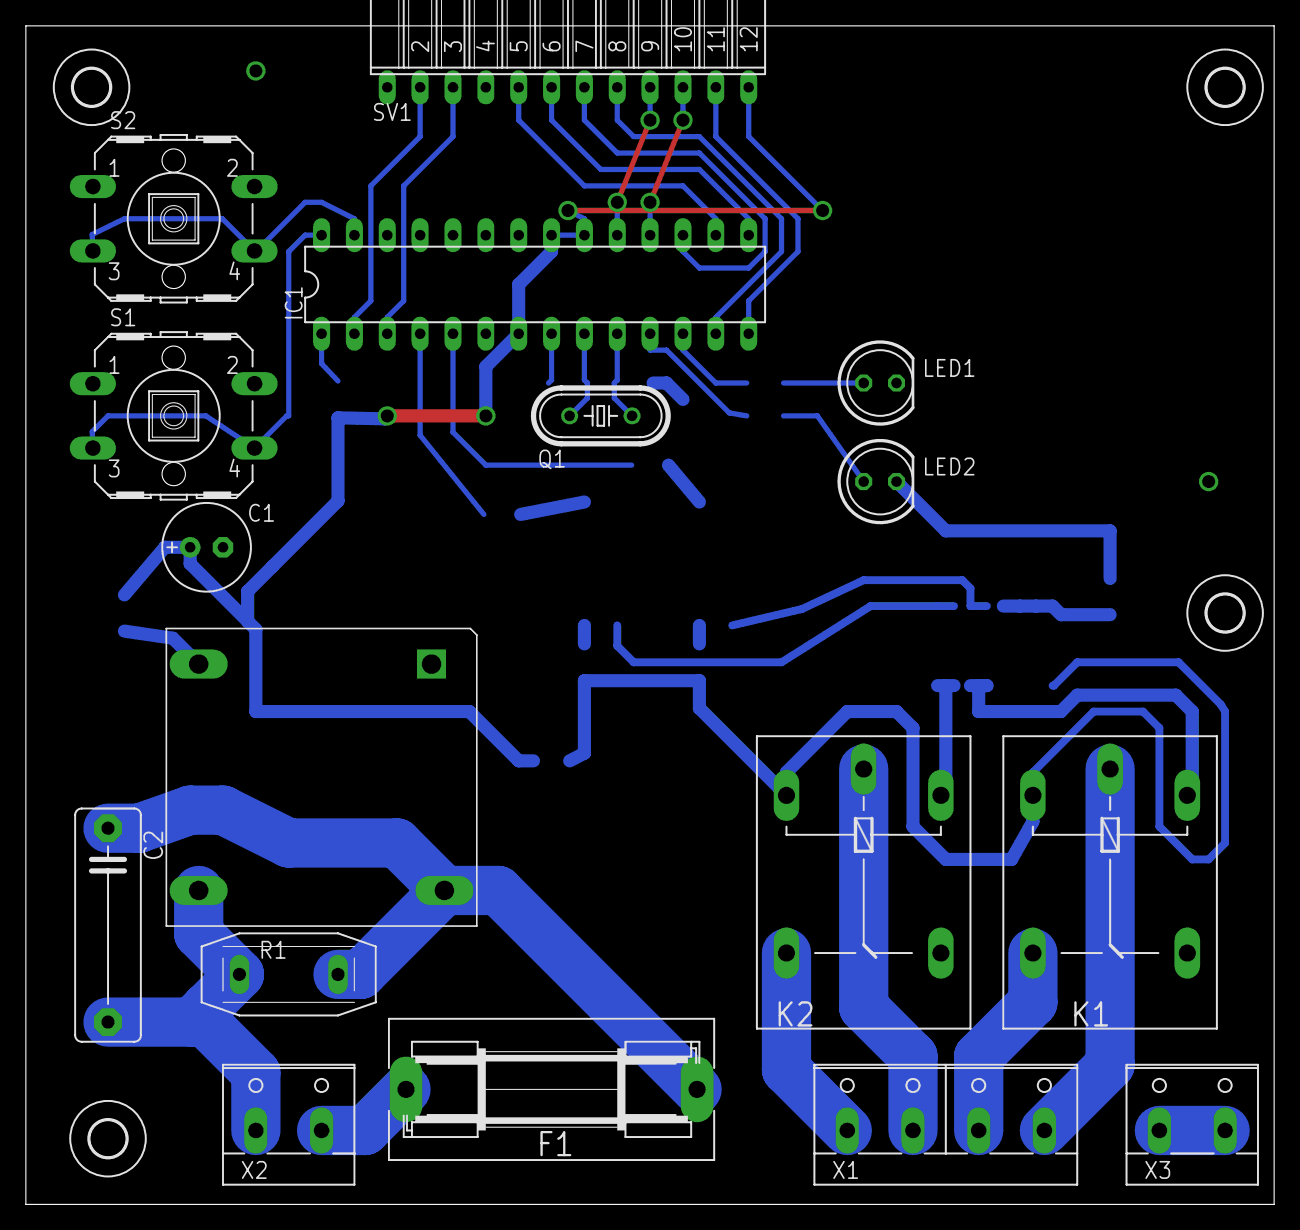
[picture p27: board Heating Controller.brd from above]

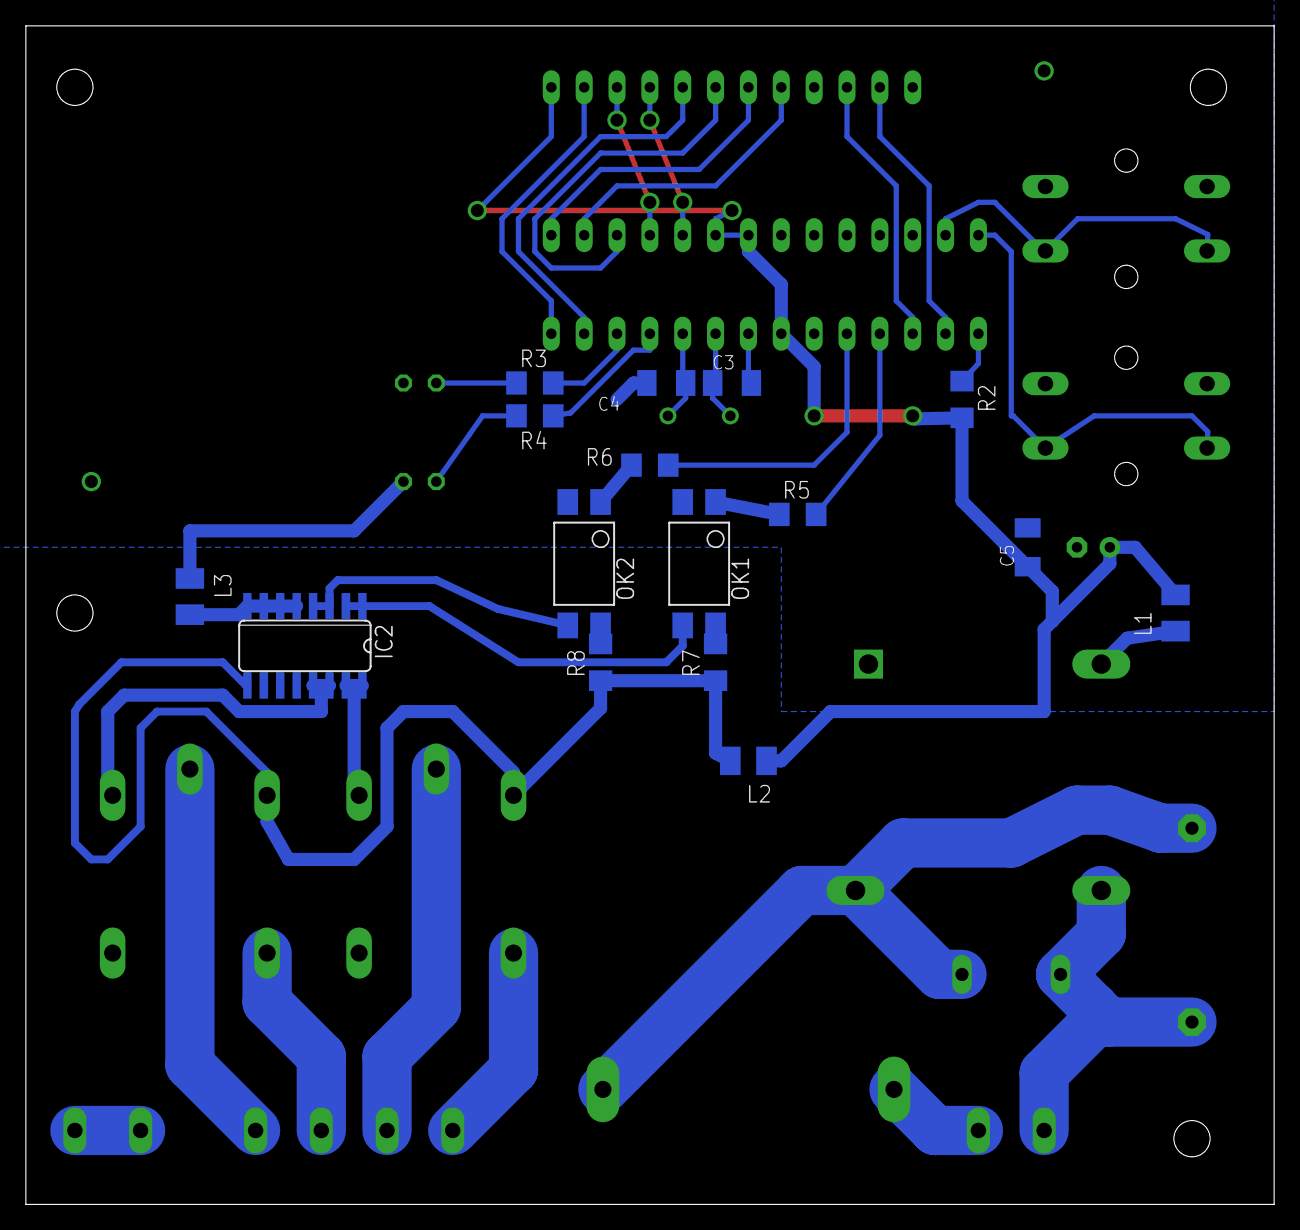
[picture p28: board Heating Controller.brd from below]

Board: 2 copper layers, 96.5 x 91.1 mm, 37 parts (16 on the bottom side), 41 nets.

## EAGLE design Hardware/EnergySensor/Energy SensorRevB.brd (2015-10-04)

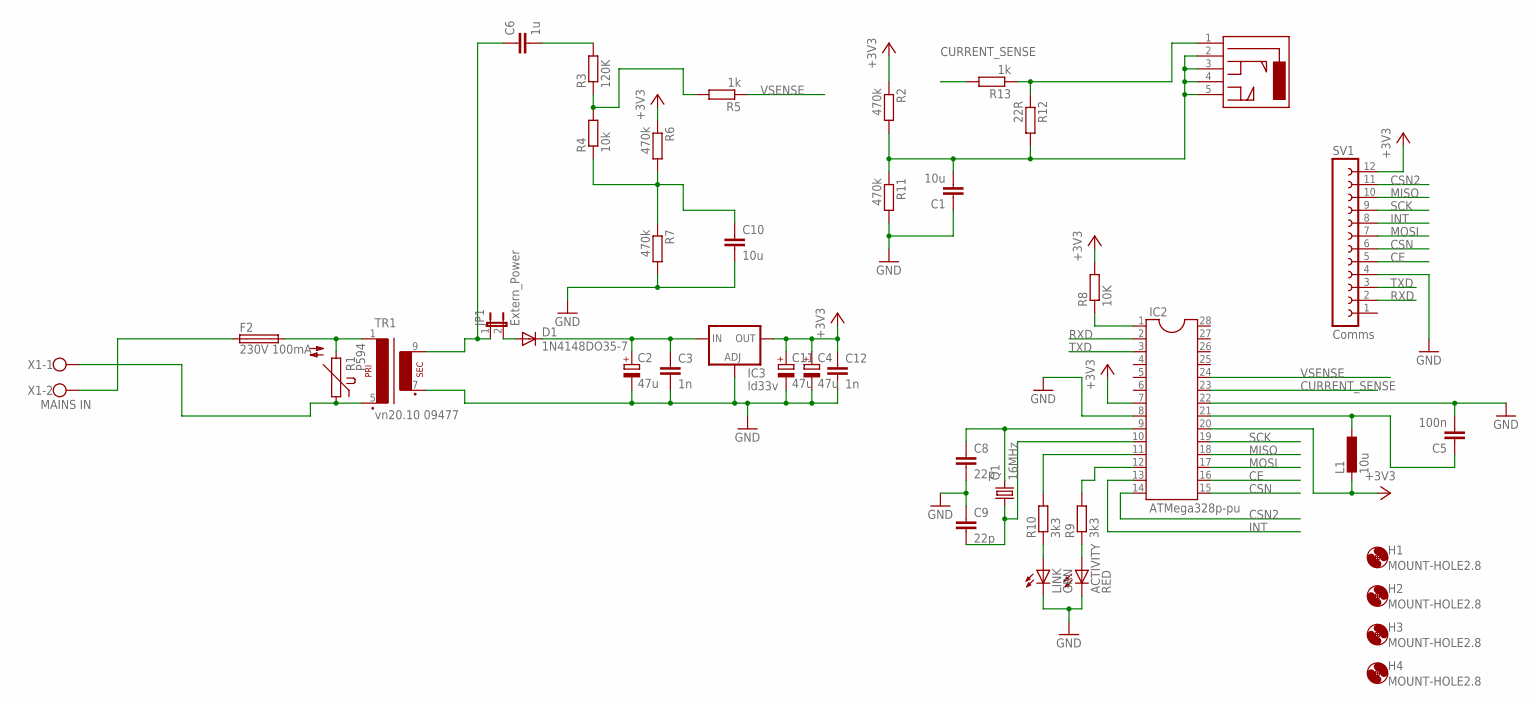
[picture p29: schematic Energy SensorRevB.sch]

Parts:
ACTIVITY: RED; LED5MM
C1, C10: 10u; C1206K
C2: 47u; E3,5-10
C3, C12: 1n; C025-025X050
C4, C11: 47u; E3,5-8
C5: 100n; C1206K
C6: 1u; C1206K
C8, C9: 22p; C025-025X050
D1: 1N4148DO35-7; DO35-7
F2: 230V 100mA; SH22,5A
H1, H2, H3, H4: MOUNT-HOLE2.8; 2,8
IC2: ATMega328p-pu; DIL28-3
IC3: ld33v; 317TL
JP1: Extern_Power; JP1
L1: 10u; L3230M
LINK: GRN; LED5MM
Q1: 16MHz; HC49/S
R1: P594
R2, R6, R7, R11: 470k; 0207/7
R3: 120K; 0207/7
R4: 10k; R1206
R5, R13: 1k; 0207/7
R8: 10K; 0207/7
R9, R10: 3k3; 0207/7
R12: 22R; R1206
SV1: Comms; FE12W
TR1: vn20.10 09477; VV11
U$1: 3.5MMJACK
X1: MAINS IN; W237-102

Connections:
+3V3: C4.+, C11.+, C12.1, IC2.7, IC2.20, IC3.2 (OUT), L1.2, R2.1, R6.1, R8.2, SV1.12
CE: IC2.16, SV1.5
CSN: IC2.15, SV1.6
CSN2: IC2.14, SV1.11
CURRENT_SENSE: IC2.23, R13.2
GND: ACTIVITY.K (C), C1.1, C2.-, C3.2, C4.-, C5.2, C8.2, C9.1, C10.2, C11.-, C12.2, IC2.8, IC2.22, IC3.1 (ADJ), LINK.K (C), R7.2, R11.2, SV1.4, TR1.7 (S3)
INT: IC2.13, SV1.8
MISO: IC2.18, SV1.10
MOSI: IC2.17, SV1.7
unnamed: C1.2, R2.2, R11.1, R12.2, U$1.2, U$1.3, U$1.4, U$1.5
unnamed: R1.1, TR1.5 (P2), X1.1
unnamed: D1.A, JP1.2
unnamed: C6.2, R3.2
unnamed: C6.1, JP1.1, TR1.9 (S4)
unnamed: R12.1, R13.1, U$1.1
unnamed: C2.+, C3.1, D1.C, IC3.3 (IN)
unnamed: C5.1, IC2.21, L1.1
unnamed: R3.1, R4.2, R5.2
unnamed: C10.1, R4.1, R6.2, R7.1
unnamed: C8.1, IC2.9, Q1.2
unnamed: C9.2, IC2.10, Q1.1
unnamed: LINK.A, R10.1
unnamed: ACTIVITY.A, R9.1
unnamed: IC2.1, R8.1
unnamed: IC2.12, R9.2
unnamed: IC2.11, R10.2
unnamed: F2.2, R1.2, TR1.1
unnamed: F2.1, X1.2
RXD: IC2.2, SV1.2
SCK: IC2.19, SV1.9
TXD: IC2.3, SV1.3
VSENSE: IC2.24, R5.1

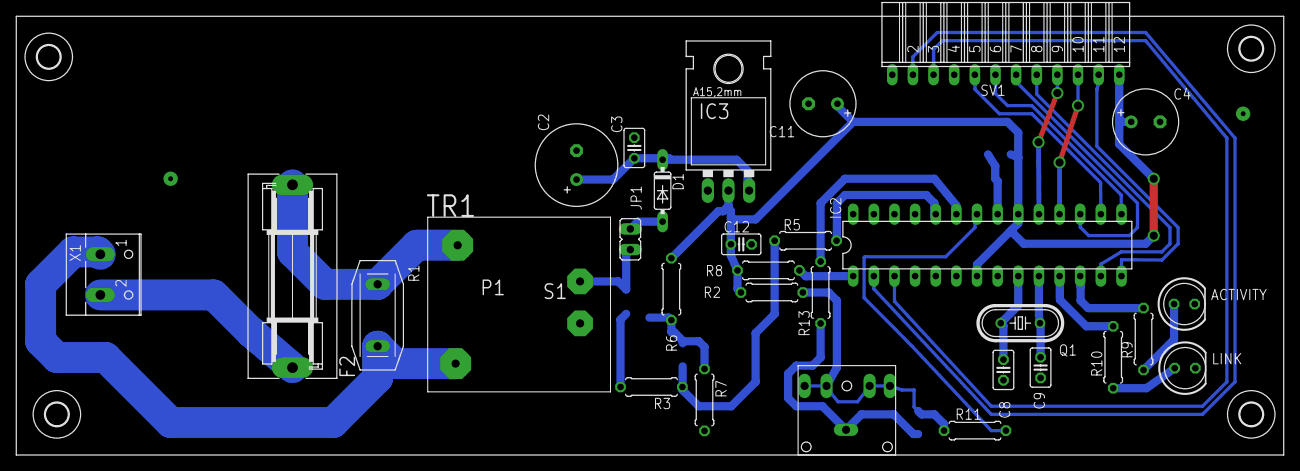
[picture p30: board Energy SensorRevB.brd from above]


Board: 2 copper layers, 156.0 x 54.0 mm, 41 parts (7 on the bottom side), 32 nets.

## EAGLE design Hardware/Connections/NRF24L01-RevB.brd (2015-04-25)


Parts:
C1: 0.1u; C1206K
EEPROM: BR25S640FJ-WE2; SO8
NRF24L01: 2X4SMDHEADER; TSM-110-XX-XXX-DV
R1, R2: 10K; R1206
R3, R4, R6: 0R; R1206
SV2: CON1; MA09-1W

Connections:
+3V3: EEPROM.3 (WPB), EEPROM.7 (HOLDB), EEPROM.8 (VCC), R2.2, R3.2, SV2.9
CE_RAD: NRF24L01.3, SV2.2
CSN_MEM: EEPROM.1 (CSB), R2.1, SV2.8
CSN_RAD: NRF24L01.4, R1.1, SV2.3
GND: C1.2, NRF24L01.1, R6.2, SV2.1
IRQ_RAD: NRF24L01.8, SV2.5
MISO: EEPROM.2 (MISO), R4.2, SV2.7
MOSI: EEPROM.5 (MOSI), NRF24L01.6, SV2.4
unnamed: C1.1, NRF24L01.2, R1.2, R3.1
unnamed: NRF24L01.7, R4.1
unnamed: EEPROM.4 (GND), R6.1
SCK: EEPROM.6 (SCK), NRF24L01.5, SV2.6


Board: 2 copper layers, 30.5 x 28.9 mm, 9 parts (0 on the bottom side), 12 nets.

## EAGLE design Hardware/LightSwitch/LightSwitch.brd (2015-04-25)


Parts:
C1: 1u; C1206K
C3: 0.1u; C1206
C4: 47u; E2,5-6E
C5: 0.1u 275V; C15B5
C6, C7: 22p; C1206
F1: 70mA; SH22,5A
H1, H2: MOUNT-HOLE4.1; 4,1
IC1: ATMEGA328P; DIL28-3
L1: BEAD; L3230M
LED1: RED; LED5MM
Q1: 8MHz; HC49U70
R1: 10k; R1206
R2: P592
R3: 3k3; R1206
S1: SWITCH; B3F-40XX
U$1: 2X4SMDHEADER; TSM-110-XX-XXX-DV
U$2: VTX-214-001-103; VTX214001103
X1: MAINS; W237-102

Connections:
+3V3: C1.1, C3.1, C4.+, IC1.7, IC1.20, IC1.21, L1.2, R1.2, U$1.2
CE_RAD: IC1.16, U$1.3
CSN_RAD: IC1.15, U$1.4
GND: C1.2, C3.2, C4.-, C6.2, C7.2, IC1.8, IC1.22, LED1.K (C), S1.3, S1.4 (P1), U$1.1, U$2.1 (GND)
MISO: IC1.18, U$1.7
MOSI: IC1.17, U$1.6
unnamed: F1.1, X1.1
unnamed: C5.1, F1.2, R2.2, U$2.4 (LIVE)
unnamed: IC1.1, R1.1
unnamed: C5.2, R2.1, U$2.3 (NEUTRAL), X1.2
unnamed: IC1.11, R3.2
unnamed: LED1.A, R3.1
unnamed: IC1.28, S1.1 (S), S1.2 (S1)
unnamed: C6.1, IC1.9, Q1.1
unnamed: C7.1, IC1.10, Q1.2
SCK: IC1.19, U$1.5
VOUT: L1.1, U$2.2 (VOUT)



Board: 2 copper layers, 70.1 x 70.0 mm, 20 parts (10 on the bottom side), 17 nets.

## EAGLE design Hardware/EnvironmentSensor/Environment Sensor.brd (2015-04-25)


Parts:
C1, C2: 22p; C1206K
C3: 1u; C1206K
C4: 100n; C1206
G1: B2430UNI
G2, G3: SL-160AA/PR
IC1: ATMEGA328P-AU; TQFP32-08
L1: 10u; L3216C
Q1: 8MHz; HC49UP
R1: 2.4M?; R1206
R2, R4, R5: 10k; R1206
R3: 27k; R1206
U$1: 2X4SMDHEADER; TSM-110-XX-XXX-DV
U$2: NPDS-9007-020; APDS-9007
U$3: SI7006A20; 3X3DFN

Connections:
ADC_LIGHT: IC1.23 ((ADC0/PCINT8)PC0), R3.1, U$2.P$3 (OUT)
CE_RAD: IC1.14 ((PCINT2/!SS!/OC1B)PB2), U$1.3
CSN_RAD: IC1.13 ((PCINT1/OC1A)PB1), U$1.4
GND: C1.2, C2.2, C3.2, C4.2, G1.-, G3.-, IC1.3 (GND), IC1.5 (GND), IC1.21 (GND), R3.2, U$1.1, U$2.P$1 (GND), U$3.P$2 (GND)
LIGHT_ENABLE: IC1.32 ((INT0/PCINT18)PD2), R1.1
MISO: IC1.16 ((PCINT4/MISO)PB4), U$1.7
MOSI: IC1.15 ((PCINT3/OC2A/MOSI)PB3), U$1.6
unnamed: C1.1, IC1.7 ((PCINT6/XTAL1/TOSC1)PB6), Q1.1
unnamed: C2.1, IC1.8 ((PCINT7/XTAL2/TOSC)PB7), Q1.2
unnamed: IC1.29 ((!RESET!/PCINT14)PC6), R2.2
unnamed: G2.-, G3.+
unnamed: R1.2, U$2.P$6 (SD)
unnamed: C4.1, IC1.18 (AVCC), IC1.20 (AREF), L1.1
SCK: IC1.17 ((SCK/PCINT5)PB5), U$1.5
SCL: IC1.28 ((ADC5/SCL/PCINT13)PC5), R5.2, U$3.P$6 (SCL)
SDA: IC1.27 ((ADC4/SDA/PCINT12)PC4), R4.2, U$3.P$1 (SDA)
VCC: C3.1, G1.+, G1.+@1 (+), G1.+@2 (+), G1.+@3 (+), G1.+@4 (+), G2.+, IC1.4 (VCC), IC1.6 (VCC), L1.2, R2.1, R4.1, R5.1, U$1.2, U$2.P$4 (VDD), U$3.P$5 (VDD)



Board: 2 copper layers, 34.0 x 57.0 mm, 18 parts (3 on the bottom side), 17 nets.

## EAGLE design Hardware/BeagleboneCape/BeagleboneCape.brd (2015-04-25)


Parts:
C1: 1u; C025-025X050
C2: 8.2p; C025-025X050
LED1: Assoc; LED5MM
LED2: ON_SLEEP; LED5MM
NRF24L01: NRF1; 2X04
P8: HEADER1; 2X23
P9: HEADER2; 2X23
R1, R2, R3: 110R; 0207/7
XB1: XBEE-PRO

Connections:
3.3V: C1.1, C2.1, NRF24L01.2, P9.3, P9.4, R3.1, XB1.1 (VCC)
5.0V: P9.7, P9.8
ASSOC: LED1.A, XB1.15 (ASSOC/DIO5)
BB_RX: P9.26, XB1.2 (DOUT)
BB_TX: P9.24, XB1.3 (DIN/!CONFIG)
CE: NRF24L01.3, P9.27
CSN: NRF24L01.4, P9.25
GND: C1.2, C2.2, NRF24L01.1, P8.1, P8.2, P9.1, P9.2, P9.43, P9.44, P9.45, P9.46, R1.1, R2.1, XB1.10 (GND), XB1.14 (VREF)
IRQ: NRF24L01.8
MISO: NRF24L01.7, P9.29
MOSI: NRF24L01.6, P9.30
unnamed: LED1.K (C), R1.2
unnamed: R3.2, XB1.5 (!RESET)
unnamed: LED2.K (C), R2.2
ON_SLEEP: LED2.A, XB1.13 (ON/!SLEEP)
SCK: NRF24L01.5, P9.31


Board: 2 copper layers, 73.6 x 58.1 mm, 11 parts (0 on the bottom side), 15 nets.

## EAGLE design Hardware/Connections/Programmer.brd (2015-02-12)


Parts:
LSP1: MCS10B
SV1: ICSP; MA03-2
SV2: COMMS; MA12-1W

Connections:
GND: SV1.6, SV2.4
MISO: SV1.1, SV2.10
MOSI: SV1.4, SV2.7
RESET: LSP1.MP, SV1.5
SCK: SV1.3, SV2.9
VCC: SV1.2, SV2.12

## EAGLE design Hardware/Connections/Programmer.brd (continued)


Board: 2 copper layers, 18.5 x 34.0 mm, 3 parts (0 on the bottom side), 6 nets.

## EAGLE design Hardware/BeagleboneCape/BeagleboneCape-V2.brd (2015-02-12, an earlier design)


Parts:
C1: 1u; C1206
C2: 8.2p; C1206
LED1: Assoc; 1206
LED2: ON_SLEEP; 1206
NRF24L01: NRF1; TSM-110-XX-XXX-DV
P8: HEADER1; 2X23
P9: HEADER2; 2X23
R1, R2, R3: 110R; R1206
XB1: XBEE-PRO

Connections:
3.3V: C1.1, C2.1, NRF24L01.2, P9.3, P9.4, R3.1, XB1.1 (VCC), XB1.1-1 (VCC)
5.0V: P9.7, P9.8
ASSOC: LED1.A, XB1.15 (ASSOC/DIO5), XB1.15-1 (ASSOC/DIO5)
BB_RX: P9.26, XB1.2 (DOUT), XB1.2-1 (DOUT)
BB_TX: P9.24, XB1.3 (DIN/!CONFIG), XB1.3-1 (DIN/!CONFIG)
CE: NRF24L01.3, P9.27
CSN: NRF24L01.4, P9.25
GND: C1.2, C2.2, NRF24L01.1, P8.1, P8.2, P9.1, P9.2, P9.43, P9.44, P9.45, P9.46, R1.1, R2.1, XB1.10 (GND), XB1.10-1 (GND), XB1.14 (VREF), XB1.14-1 (VREF)
IRQ: NRF24L01.8, P9.28
MISO: NRF24L01.7, P9.29
MOSI: NRF24L01.6, P9.30
unnamed: LED1.C, R1.2
unnamed: R3.2, XB1.5 (!RESET), XB1.5-1 (!RESET)
unnamed: LED2.C, R2.2
ON_SLEEP: LED2.A, XB1.13 (ON/!SLEEP), XB1.13-1 (ON/!SLEEP)
SCK: NRF24L01.5, P9.31


Board: 2 copper layers, 73.6 x 58.1 mm, 11 parts (0 on the bottom side), 16 nets.

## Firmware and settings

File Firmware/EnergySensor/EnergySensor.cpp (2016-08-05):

/*
* EnergySensor.cpp
*
* Created: 16/03/2015 09:09:38
*  Author: Ali
* Energy calculations based on a modified version of https://github.com/openenergymonitor/EmonLib licensed by GNU GPL I do not claim to have developed them fully myself. 
*/


#include <avr/io.h>
#include <string.h>



#define ADC_FACTOR 0.00322265625 // 3.3/1024

#include "EnergySensorRevA.h"
#define BAUD 9600
#include <util/setbaud.h>
#include "Timing.h"

#include "MQTTSN.h"
#include "SensorNet.h"


void adc_init();
uint16_t  adc_read(uint8_t ch);
int USART0SendByte (char c, FILE *stream);
int USART0ReceiveByte(FILE *stream);
void USARTinit(void);
void connectedLed(uint8_t level);
void pendingLed(uint8_t level);
void setup(void);
void calcPwr(double &power, double &pf);



FILE * usart0_str;
RF24 radio;
SensorNet network(radio, MAC_SUFF_HEX);
MQTTSN app(network,THIS_MQTTCLIENTID, MAC_SUFF_HEX);


int main(void)
{
	delay(2000); // wait two seconds for power supply to stabilize.THIS IS COMPULSORY OR CONFIG IN SETUP GOES MAD!
	setup();
	while(1)
	{
		for (int c = 0; c<120;c++) // report every minute or so. ( 120 * 500msec) =
		{
			delay(500); // wait one second
			app.tick(); // tick the network to route any packets or pings.
		}
		//take three readings.
		double pow1, pow2,pow3;
		double pf1, pf2, pf3;
		calcPwr(pow1, pf1);
		calcPwr(pow2, pf2);
		calcPwr(pow3, pf3);
		//average them.
		double averagePower =(pow1+pow2+pow3) /3;
		double averagePF = (pf1+pf2+pf3)/3;
		
		//strip to 1 sig figure.
		long temp =(long) (averagePower *10.0); // shift to the left by 1dp and by putting into int the extra values are lost.
		averagePower = temp /10.0; //shift back and put into the original value.
		
		//strip to  2 sig figure.
		temp =(	long)(averagePF * 100.0); // shift to the left by 2dp and by putting into int the extra values are lost.
		averagePF = temp /100.0;
		
		
		//buffers to store text of values.
		char power [7];// maximum wattage (100A ( current meter max) * 300V (we definetley don't want any rms higher than that.)) 30000.0 (6+1 digits) (log2(300000) = at least 19 bits to store as an unsigned number.
		char pf [4]; // 0.01 precision + 1
		//shift so no DP. ( saves space)
		long	avPFShift = averagePF * 100; // shift to left 2dp. will give 0.01 precision, will never be zero.
		long avPowerShift = averagePower * 10; // shift left 1dp. will give 0.1W precision
		
		//convert to strings
		ltoa(avPowerShift,power, 10);
		ltoa(avPFShift, pf, 10);


		// make sure we are still connected.
		while (!(app.currentState == STATE_ACTIVE) | (app.currentState == STATE_WAIT_PINGRESP))
		{
			connectedLed(LOW);
			//_delay_ms(2000); //dont spam the network with reconnections.
			app.connect();
			_delay_ms(2500); //wait for response.
			app.tick();
		}
		connectedLed(HIGH);
		char  payload [10];
		//format the final payload.
		sprintf((char*)payload,"%s,%s", power, pf);
		payload [10] = 0x00;
		// get the size of the payload
		uint8_t plen = (unsigned)strlen(payload);
		//get the id of the topic we are going to publish to.
		uint16_t topicid = app.gettopicid((unsigned char*)"d/"MAC_SUFF"/"ID1"/"TOPIC_STATUS_UPDATE, 0x0C);
		if (topicid != 0)
		{
			//send the message.
			app.publish(topicid,(unsigned char*)payload,plen);
		}

	}
	
}
void calcPwr(double &power, double &pf)
{
	unsigned int timeout = 20000;
	//how many zero crossings to measure
	unsigned int crossingCount = 20;
	//initial offset for filter at 1024/2
	double filterV = 512;
	double filterA = 512;
	//the number of times zero has been crossed
	unsigned int currentCrossCount = 0;
	
	//the number of samples taken.
	unsigned long numberOfSamples = 0;
	
	
	bool lastVCross;
	bool checkVCross = false;
	bool go = false;
	int initialV;
	double summedV = 0, summedA=0, summedP = 0;
	unsigned long start = Timing::millis();
	
	while (go == false)
	{//check if voltage is around 0 mark.
		initialV = adc_read(VOLTAGE_CH);
		if ((initialV < (1024*0.55)) &&(initialV >(1024*0.45) ))
		{
			go = true;
		}//if not found in time just continue
		if ((Timing::millis()-start) > timeout)
		{
			go = true;
		}
	}
	start = Timing::millis();
	
	
	while ((currentCrossCount < crossingCount) && ((Timing::millis()-start)<timeout))
	{
		numberOfSamples++;
		//read the instantaneous voltage and current
		int instV = adc_read(VOLTAGE_CH);
		int instA = adc_read(CURRENT_CH);
		//low pass digital filter
		filterV = filterV + ((instV-filterV)/1024);
		double filteredV = instV - filterV;
		
		filterA = filterA + ((instA-filterA)/1024);
		double filteredA = instA - filterA;
		
		double sqV= filteredV * filteredV;
		double sqA= filteredA * filteredA;
		summedV += sqV;
		summedA += sqA;
		summedP += filterA * filterV;
		
		
		
		
		
		lastVCross = checkVCross;
		if (instV > initialV) checkVCross = true;
		else checkVCross = false;
		if (numberOfSamples==1) lastVCross = checkVCross;
		if (lastVCross != checkVCross) currentCrossCount++;
	}
	printf("Number of samples: %lu\n", numberOfSamples);
	printf("Number of crosses: %i\n", currentCrossCount);
	//scale the voltage to the voltage at the pin then multiply it by a calibration factor, this was worked out with use of an oscilloscope to ensure it is accurate representation of measurement.
	int Tout  = (sqrt(summedV / numberOfSamples))  * ADC_FACTOR * 199.6; 
	
	double rmsARaw =sqrt(summedA / numberOfSamples); //-2.9

	if (rmsARaw < 0)
	rmsARaw =0;
	//same as with the voltage, this is a calibration factor that is worked out with use of an oscilloscope.
	double AAvg = (rmsARaw * ADC_FACTOR) * 90.9  ;

	//assign final variables to output.
	power = AAvg * Tout;
	pf = 1;

	int intAAvg = AAvg * 10.0;
	int intpower = power * 10.0;
	printf("Current (RMS)         : %dA\n", intAAvg);
	printf("Voltage (RMS)         : %dV\n", Tout);
	printf("Power (RMS)			  : %dW\n", intpower);
}
void setup(void)
{
	USARTinit(); //enable serial output;
	Timing::init();// start the timer - used for the millis function (rough time since powered on);
	adc_init();
	network.setup(THIS_LEVEL, THIS_DEV); //ensure network is setup before any MQTT work is done.
	STATUS_LED_1_DDR |= (1<<STATUS_LED_1); //STATUS1_LED
	STATUS_LED_2_DDR |= (1<<STATUS_LED_2); //STATUS2_LED

	connectedLed(LOW);
	pendingLed(LOW);

}
void adc_init()
{
	/* AREF = AVcc*/
	//	ADMUX |= (1<<REFS0);
	/*AREF = (ARef Pin Voltage)*/
	ADMUX &=~(1<<REFS0);
	ADMUX &=~(1<<REFS1);
	//ADMUX=0b11XXXXXX
	
	/*right adjust result */
	ADMUX &= ~(1<<ADLAR);


	/* Set Prescaler for ADC Speed (ADC MAX FOR GOOD QUALITY = 200KHz*/
	// 10M clock /64 =156.250KHz 110
	ADCSRA |=(1<<ADPS2);  //set to 1
	ADCSRA |=(1<<ADPS1); //set to 1
	ADCSRA &=~(1<<ADPS0);  //set to 0
	
	
	ADCSRA |= (1<<ADEN); //Enable the ADC now it has been configured
}
// read adc value
uint16_t adc_read(uint8_t ch)
{
	// select the corresponding channel 0~7
	// ANDing with '7' will always keep the value
	// of 'ch' between 0 and 7
	ch &= 0b00000111; // AND operation with 7
	ADMUX = (ADMUX & 0xF8)|ch; // clears the bottom 3 bits before ORing

	// start single conversion
	// write '1' to ADSC
	ADCSRA |= (1<<ADSC);

	// wait for conversion to complete
	// ADSC becomes '0' again
	// till then, run loop continuously
	while(ADCSRA & (1<<ADSC));

	return (ADC);
}
int USART0SendByte (char c, FILE *stream)
{
	if (c == '\n')
	USART0SendByte('\r', stream);
	
	// Wait for the transmit buffer to be empty
	while ( !( UCSR0A & (1<<UDRE0)) );
	
	// Put our character into the transmit buffer
	UDR0 = c;
	
	return 0;
}
int USART0ReceiveByte(FILE *stream)
{
	uint8_t u8Data;
	// Wait for byte to be received
	while(!(UCSR0A&(1<<RXC0))){};
	u8Data=UDR0;
	//echo input data
	USART0SendByte(u8Data,stream);
	// Return received data
	return u8Data;
}
void USARTinit(void)
{
	//set baud rate.
	UBRR0H = UBRRH_VALUE;
	UBRR0L = UBRRL_VALUE;
	
	#if USE_2X
	UCSR0A |= (1<<U2X0);
	#else
	UCSR0A &= ~(1<<U2X0);
	#endif
	
	//enable RX & TX
	UCSR0B = (1<<RXEN0) | (1<<TXEN0);

	//set frame format, 8 data, 1 stop
	//1 stop bit
	UCSR0C &= ~(1<<USBS0);
	//8 data
	UCSR0C |=  (1<<UCSZ00)|(1<<UCSZ01);
	
	usart0_str = fdevopen(USART0SendByte, USART0ReceiveByte);
	stdin=stdout=usart0_str;
}
void connectedLed(uint8_t level)
{
	if (level == HIGH)
	{
		STATUS_LED_1_PORT |= (1<<STATUS_LED_1);
	}
	else
	{
		STATUS_LED_1_PORT &= ~(1<<STATUS_LED_1);
	}
}
void pendingLed(uint8_t level)
{
	if (level == HIGH)
	{
		STATUS_LED_2_PORT |= (1<<STATUS_LED_2);
	}
	else
	{
		STATUS_LED_2_PORT &= ~(1<<STATUS_LED_2);
	}
}

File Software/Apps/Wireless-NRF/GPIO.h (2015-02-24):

/* 
 * File:   GPIO.h
 * Author: alistair
 *
 * Created on 26 January 2015, 14:34
 *  The GPIO Class handles the Hardware calls to the kernel for GPIO Access.
 */

#ifndef GPIO_H
#define	GPIO_H

class GPIO {
public:

#define GPIO_DDR_OUT 1
#define GPIO_DDR_IN 0
#define GPIO_VAL_HIGH 1
#define GPIO_VAL_LOW 0

    GPIO();
    virtual ~GPIO();
    static void open(int port, int DDR);
    static void close(int port);
    static int read(int port);
    static void write(int port, int value);
private:

};

#endif	/* GPIO_H */

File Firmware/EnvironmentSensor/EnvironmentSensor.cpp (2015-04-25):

/*
* EnvironmentSensor.cpp
*
* Created: 29/03/2015 06:45:32
*  Author: Ali
*/


#include <avr/io.h>

#include "EnvironmentSensorRevA.h"
#define BAUD 9600
#include <util/setbaud.h>
#include <util/twi.h>
#include "Timing.h"

#include "MQTTSN.h"
#include "SensorNet.h"



void adc_init();
void i2c_init();
uint16_t  adc_read(uint8_t ch);
int USART0SendByte (char c, FILE *stream);
int USART0ReceiveByte(FILE *stream);
void USARTinit(void);
void setup(void);
uint16_t readALS(void);
uint8_t getHumid(void);
uint8_t getTemp(void);

FILE * usart0_str;
RF24 radio;
SensorNet network(radio, MAC_SUFF_HEX);
MQTTSN app(network,THIS_MQTTCLIENTID, MAC_SUFF_HEX);




int main(void)
{
	setup();
	
	while(1)
	{
		// sleep for a period of time ( 2 mins)
		for (int c = 0; c<120;c++) // report every minute or so. ( 120 * 500msec) =
		{
			delay(500); // wait 1/2 second
			app.tick(); // tick the network to route any packets or pings.
		}
				for (int c = 0; c<120;c++) // report every minute or so. ( 120 * 500msec) =
				{
					delay(500); // wait 1/2 second
					app.tick(); // tick the network to route any packets or pings.
				}
		uint16_t ALS = readALS();
		uint8_t humid = getHumid();// make sure the humidity is read first, the temperature is read by the chip when measuring humidity. so to reduce time a special command can be issued after the humidity for quick temp readouts.
		uint8_t temp = getTemp();
		char humidC[4];
		char ALSC[6]; //10,000 max value
		char tempC[4];
		ltoa(humid, humidC, 10);
		ltoa(ALS,ALSC, 10);
		ltoa(temp, tempC, 10);
		printf("Humidity: %s\n", humidC);
		printf("ALS:      %s\n", ALSC);
		printf("Temp:     %s\n", tempC);
		while (app.currentState != STATE_ACTIVE)
		{
			//_delay_ms(2000); //dont spam the network with reconnections.
			app.connect();
			_delay_ms(2500); //wait for response.
			app.tick();
		}
		uint8_t	pub1id = app.gettopicid((unsigned char*)"d/"MAC_SUFF"/"ID1"/"TOPIC_STATUS_UPDATE, 0x0C);
		uint8_t	pub2id = app.gettopicid((unsigned char*)"d/"MAC_SUFF"/"ID2"/"TOPIC_STATUS_UPDATE, 0x0C);
		uint8_t	pub3id = app.gettopicid((unsigned char*)"d/"MAC_SUFF"/"ID3"/"TOPIC_STATUS_UPDATE, 0x0C);
		
		app.publish(pub1id,(unsigned char*)humidC, strlen(humidC));
			delay(200); // wait 1/5 second
		app.publish(pub2id,(unsigned char*)tempC, strlen(tempC));
			delay(200); // wait 1/5 second
		app.publish(pub3id,(unsigned char*)ALSC, strlen(ALSC));
			delay(200); // wait 1/5 second
		// on wake get the readings from sensors: light level, humidity, temperature.
		// connect to the wireless Net and send sensor data.
		// go back to sleep.
	}
}
uint16_t readALS()
{
	//turn on the sensor.
	
	ALS_ENABLE_PORT &= ~(1<< ALS_ENABLE_PIN);
	//need a minimum of 0.2milliseconds for the sensor to activate fully.
	_delay_ms(200);
	uint16_t reading1 =  adc_read(ALS_CH);
	_delay_ms(200);
	uint16_t reading2 =  adc_read(ALS_CH);
	_delay_ms(200);
	uint16_t reading3 =  adc_read(ALS_CH);
	_delay_ms(200);
	printf("%d, %d, %d\n", reading1, reading2, reading3);
	// 0.25V -> 10 lux
	// 1.25V -> 100000 lux
	
	//turn off the sensor.
	ALS_ENABLE_PORT |= (1<< ALS_ENABLE_PIN);
	//need a minimum of 0.2milliseconds for the sensor to deactivate fully.
	_delay_ms(200);
	uint16_t  averageRead = ((reading1+reading2+reading3)/3.0);
	//rather than use lookup table, have defined set areas of linearity. this is due to datasheet not being fully concise.
	if (averageRead <77)
	return 10; // return min value.
	else if (averageRead < 167)
	return (averageRead * 0.5988);
	else if (averageRead < 251)
	return (averageRead * 3.9840);
	else if (averageRead < 335)
	return (averageRead * 29.8507);
	else
	return 0x2710; // return max value 10,000
}
void setup()
{
	USARTinit(); //enable serial output;
	Timing::init();// start the timer - used for the millis function (rough time since powered on);
	adc_init();
	i2c_init();
	network.setup(THIS_LEVEL, THIS_DEV); //ensure network is setup before any MQTT work is done.
	ALS_ENABLE_DDR |= (1<<ALS_ENABLE_PIN); //set als enable pin as output.
	
}
void adc_init()
{
	/* AREF = AVcc*/
	//	ADMUX |= (1<<REFS0);
	/*AREF = (ARef Pin Voltage)*/
	ADMUX &=~(1<<REFS0);
	ADMUX &=~(1<<REFS1);
	
	/*right adjust result */
	ADMUX &= ~(1<<ADLAR);


	/* Set Prescaler for ADC Speed */
	//111 = CLK / 128
	//ADCSRA |=(1<<ADPS2);
	//ADCSRA |=(1<<ADPS1);
	//ADCSRA |=(1<<ADPS0);
	//128 is too slow.
	//set to /2 max speed
	ADCSRA &=~(1<<ADPS2);
	ADCSRA &=~(1<<ADPS1);
	ADCSRA |=(1<<ADPS0);
	
	
	ADCSRA |= (1<<ADEN); //Enable the ADC now it has been configured
}
void i2c_init(){
	//Si7006 max clock speed is 400KHz, <100KHz with minimal clock skew.
	// SCL speed = F_CPU / (16 + 2(TWBR)*prescaler))
	// running at 80KHz with a 8MHz clock, the best values are 42 bit rate and 1 prescaler.
	TWBR = 0x2a; // set bit rate to 42.
	TWSR &= ~((1<<TWPS1) | (1<<TWPS0)); // set prescaler to 1, 00
}
// read adc value
uint16_t adc_read(uint8_t ch)
{
	// select the corresponding channel 0~7
	// ANDing with '7' will always keep the value
	// of 'ch' between 0 and 7
	ch &= 0b00000111; // AND operation with 7
	ADMUX = (ADMUX & 0xF8)|ch; // clears the bottom 3 bits before ORing

	// start single conversion
	// write '1' to ADSC
	ADCSRA |= (1<<ADSC);

	// wait for conversion to complete
	// ADSC becomes '0' again
	// till then, run loop continuously
	while(ADCSRA & (1<<ADSC));

	return (ADC);
}
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

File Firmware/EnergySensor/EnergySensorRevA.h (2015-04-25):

/*
 * PowerOutletRevA.h
 *
 * Created: 16/03/2015 09:10:49
 *  Author: Ali
 */ 


#ifndef POWEROUTLETREVA_H_
#define POWEROUTLETREVA_H_

//check the global compile time variables have been defined.
#ifndef HIGH
# warning "HIGH LEVEL NOT DEFINED"
#endif
#ifndef LOW
# warning "LOW LEVEL NOT DEFINED"
#endif
#ifndef CSN
#warning "CSN PIN NOT DEFINED"
#endif
#ifndef CE
#warning "CSN PIN NOT DEFINED"
#endif
#ifndef F_CPU
#warning "CPU Speed NOT DEFINED"
#endif


//INDIVIDUAL DEVICE ID
#define MAC_SUFF "AEAEAE"
#define MAC_SUFF_HEX 0xAEAEAE
//this should be assigned dynamically but for time being will be manual
#define THIS_LEVEL 1
#define THIS_DEV 2
#define THIS_MQTTCLIENTID 0x45

#define STATUS_LED_1 PORTD5 //OUT1_LED
#define STATUS_LED_2 PORTD6 //OUT2_LED

#define STATUS_LED_1_DDR DDRD //OUT1_LED
#define STATUS_LED_2_DDR DDRD //OUT2_LED

#define STATUS_LED_1_PORT PORTD //OUT1_LED PORT - this will be connection status???
#define STATUS_LED_2_PORT PORTD //OUT2_LED PORT - this will be state change pending????

/* PIN DEFINITIONS */
//MQTT ID Mappings (ASCII VALUE FOR NUMBER)
#define ID1 "1" //0x31 //1 maps to Power
#define ID2 "2" //0x32 //2 maps to Power Factor.

#define ID1_PIN  1 //ADC CHANNEL 1 (PIN 24)
#define ID2_PIN  0 //ADC CHANNEL 0 (PIN 23)

//for readability
#define VOLTAGE_CH ID1_PIN
#define CURRENT_CH ID2_PIN


/* PIN DEFINITIONS */



#endif /* POWEROUTLETREVA_H_ */

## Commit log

2014-12-04 Initial Commit of current PCBs
    [BeagleboneCape.sch, Energy Sensor.sch, Environment Sensor.sch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]
2014-12-04 Updated NRF24L01 pcb silkscreen and exported to PDF files.
    [NRF24L01-BOM.csv, NRF24L01.brd]
2014-12-08 Added Linux From Scratch (LFS) style build scripts and files. However the build scripts are found to be flawed.
    [BeageboneCape.brd]
2015-01-20 updated PoE Schematic slightly and added eagle project file. Updated Readme to explain current directory structure
    [PoE.brd, PoE.sch]
2015-01-20 updated build scripts for a more automated procedure. Additionally applied new packages. However the build script is missing creation of a working SPI dtb. (see https://github.com/RobertCNelson/dtb-r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
2015-01-20 fixed mosquitto location on startup script. fixed script not setting executable on services fixed startupscript not setting LEDs to off
2015-01-24 fixed to get UART working with dtb. Enabled the removal of the dtb-rebuilder dependency.
2015-01-25 Removed Adafruit Beaglebone Sample ( was used for reference only). Finished beaglebone board Connecting NRF24L01 through SPI1 and Xbee to UART1 Generated PCB Pdf Files.
    [BeageboneCape.brd, BeagleboneCape.brd, BeagleboneCape.sch]
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2015-01-25 Updated PDF PCB files with Document outline mark. Fixed missing Name for NRF connector. Updated BOM to be correctly formatted.
    [NRF24L01-BOM.csv, NRF24L01.brd, NRF24L01.sch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]
2015-01-30 updated cape after printout and generated V2 ( Rev B) SMD Version (prding completion on conversion).
    [BeagleboneCape-V2.brd, BeagleboneCape-V2.sch]
2015-01-30 updated V2 ( Rev B) Board to use SMD only components where possible. Using 1206 Components
    [BeagleboneCape-V2.brd, BeagleboneCape-V2.sch]
2015-01-30 updated XBEE Schematic. Added 3 Extra Pins for Serial protocol
    [XBEE.brd, XBEE.sch]
2015-02-01 added missing components to XBEE schematic
    [XBEE.brd, XBEE.sch]
2015-02-01 added high power components for energy sensor. transformer needs to be sorted.
    [Energy Sensor.sch]
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2015-02-02 added execution time in script summary. removed need for menuconfig for busybox added install of apache startup script allowed sshd blank passwords set mosquitto pid file to fix service script not re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
2015-02-03 updated POE design. missing power circuitry and suitable rj45 connector
    [PoE.brd, PoE.sch]
2015-02-03 added marker to board file to allow for better silkscreen alignment
    [BeagleboneCape-V2.brd]
2015-02-03 initial mock up of board. still need to check silkscreen arrangement
    [Energy Sensor.brd, Energy Sensor.sch]
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2015-02-06 update schematics, added switchmode psu to heating controller. fixed line endings for existing files
    [BeagleboneCape-BOM.csv, Energy Sensor.brd, Energy Sensor.sch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]
2015-02-06 moved eagle custom parts to repo to allow for easier portability when working on designs
    [Energy Sensor.brd]
2015-02-06 updated fuse locations and updated missing values
    [Energy Sensor.brd, Energy Sensor.sch]
2015-02-06 initial mockup of heating controller
    [Heating Controller.sch]
2015-02-06 created initial mock up of power outlet schematic
    [Power Outlet.sch]
2015-02-06 created a programmer to allow for programming through the comms port
    [Programmer.sch]
2015-02-12 updated to fix bug where spi would not fully work. due to other enabled devices.
2015-02-12 updated beaglebone cape and added pdf build files
    [BeagleboneCape-V2.brd]
2015-02-12 added board and etch pdf for programmer attachment
    [Programmer.brd]
2015-02-12 updated to fuse and varistor arrangements
    [Energy Sensor.brd, Energy Sensor.sch]
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2015-02-12 Updated missing values for connectors
    [Programmer.sch]
2015-02-12 added heating controller board
    [Heating Controller.brd]
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2015-02-12 initial mock up of board. added optocouplers to help increase isolation from mains
    [Power Outlet.brd, Power Outlet.sch]
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2015-02-23 added optocoupled output to add extra layer of isolation
    [Heating Controller.brd, Heating Controller.sch]
2015-02-23 added basic components still awaiting Vreg and sensor devices
    [Environment Sensor.sch]
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2015-02-24 Updated to make program take command line arguments correctly
    [main.cpp]
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2015-03-03 further updating of files however bug where does not seem to subscribe correctly.
    [PowerOutletV1.h]
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2015-03-03 Updated to use new device notation for shorter topics
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2015-03-10 updated Fuse Holder for part that is in stock. Updated wrong Processor footprint also fixed screw terminals wrong way round
    [Power Outlet.brd, Power Outlet.sch]
2015-03-10 Updated wrong fuse holder and processor footprint
    [Heating Controller.brd, Heating Controller.sch]
2015-03-10 updated wrong fuse holder and incorrect terminal and processor mounts
    [Energy Sensor.brd, Energy Sensor.sch]
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2015-03-11 updated to fix incorrect pin assignments
    [PowerOutletV1.h]
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2015-03-11 updated to correct componnent values and minor tweaks
    [Power Outlet.brd, Power Outlet.sch]
2015-03-11 Updated to be slightly smaller and to have bypass capacitor for more stable operation
    [NRF24L01-RevB.brd, NRF24L01-RevB.sch]
2015-03-11 updated moved to new revision as Rev A has already been produced. Added inductor to clean output power rail.
    [Power Outlet-RevB.brd, Power Outlet-RevB.sch]
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2015-03-13 added new library to correct incorrect footprint for LTV816S
2015-03-13 updated wrong capacitor footprint, removed isolation cap as causes circuit not to function.
    [Power Outlet-RevB.brd, Power Outlet-RevB.sch]
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2015-03-15 Moved To Rev B. ( Current transducer draws too much current for power supply. Moving to Current Transformer)
    [Energy SensorRevB.brd, Energy SensorRevB.sch]
2015-03-15 updated scematic with new power regulator and 3.5mm jack connector for current meter
    [Energy SensorRevB.brd, Energy SensorRevB.sch]
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2015-03-20 Updated Rev B to reflect beneficial changes with Rev A pratical application, added noise suppressor to ARef. updated smoothing Ref Caps to match package. Added Additional Smoothing capacitors (due to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
    [Energy SensorRevB.brd, Energy SensorRevB.sch]
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2015-03-20 fixed dynamic power size message
    [EnergySensor.cpp]
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2015-03-21 added a better printout (compressed more and HEX printing correctly (2 Digits per byte)
2015-03-21 added fix where packets would be massivley huge. Added increased client support to main()
    [main.cpp]
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2015-03-21 fixed incorrect resistor footprints. Added AGND Isolation Inductor. Added Silk Text. Moved Component Labels
    [Heating Controller.brd, Heating Controller.sch]
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2015-03-21 Renamed Lighting controller to lightswitch. Updated VTX supply text
    [LightSwitch.sch, Lighting Controller.sch]
2015-03-21 created library parts for : Si7006-A20 ATMEGA328P-AU (TQFP32) APDS AMBIENT LIGHT SENSOR
    Updated Environment sensor with up to date schematic
    [Environment Sensor.sch]
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2015-03-22 updated etch and create TOP etch for print tests
    [Environment Sensor.brd]
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2015-03-26 generated Silk PDF and postscript files for silkscreen
    [NRF24L01-RevB.brd]
2015-03-28 updated net css to use new styling from http://www.lavishbootstrap.com/. Added missing Sensor pages - (edit delete new). Added support to set a sensor request to have multiple destinations
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2015-03-29 FIXED MAJOR BUG - schematic was incorrect for power measurements
    [Energy SensorRevB.brd, Energy SensorRevB.sch]
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2015-03-31 Fixed graph referencing. ( changed from container to sensorGraph) added suffix for power data for tooltip added processing of power compound data for set sensor types.
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2015-03-31 fixed incorrect optocoupler
    [Heating Controller.brd, Heating Controller.sch]
2015-04-01 MASSIVE BUG - Listening on 000 and transmitting to it would cause messages to be sent all over the place. It turned out that the address is not an address of the device but and address of the COMMUNI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
2015-04-02 updated schematic and created intial wired design for light switch
    [LightSwitch.brd, LightSwitch.sch]
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2015-04-03 updated processoor to be surface mount. created intial route for pcb tracks. Had to use dual layer board to allow for small form factor
    [LightController.brd, LightController.sch]
2015-04-03 fixed indentations, and changed wireless --> UDP wording to better show data direction changed to UDP <-- Wireless
    [main.cpp]
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2015-04-03 Fixed Bug where lights would dimly light. this was due to the ddr being written to somewhere. turned out to be wrong DDR for buttons
    [PowerOutletV1.h]
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2015-04-04 Added blank projects for initial commit of the missing PCB Firmwares
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2015-04-06 added mounting holes to include extra detail for silk
    [LightSwitch.brd, LightSwitch.sch]
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2015-04-06 updated board text to be the correct way round
    [LightSwitch.brd]
2015-04-06 updated silk for the board change, to reflect the wording orientation correction
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2015-04-07 corrected filtering to work by control type category ( output, sensor, request)
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2015-04-09 moved javascript to show correct form for sensor data to sepearte function to enable the ability to call it manually which fixes bug where on ititial load the new sensor form would not show correct d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
2015-04-09 moved mqtt ClientId assingments to board header files. Additionally fixed bug caused by same client IDs, changed each board to different clientIds
    [EnergySensor.cpp, EnergySensorRevA.h, EnvironmentSensor.cpp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]
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2015-04-09 updated Scheduler to put lastexec time into rule dbif rule is ran. also corrected filtering of what rules to process
    [main.cpp]
2015-04-09 fixed case for variables
2015-04-10 added sqlopen threaded access. added retry loop to log function. added more information to sql errors. Indented page correctly. merged some sql statements.
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2015-05-11 added manufacturing pictures, tidied code and commented. prepared for final commit ready for submission
    [ALL-BOM.xlsx]
2015-10-17 added build and install of IBM rsmb broker added RSMB startup script added sample Broker config file updated httpd version to use latest version
    [broker.cfg]
2016-01-09 started creation of RevC Beaglebone cape. - aims to add EEPROM programming capability and full support of any comms module
    [BeagleboneCape-RevC.brd, BeagleboneCape-RevC.sch]
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2016-01-11 updated KiCAD files to working set, initial schematic made using SPI0
    [Rev C.kicad_pcb, Rev C.sch, RevC.kicad_pcb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]
2016-01-12 initial mockup of board layout, removed 8 pin connector in favour of the single-module board
    [RevC.kicad_pcb, RevC.sch]
2016-01-16 updated layout to include radio header thanks to new layout tweaks
    [RevC.kicad_pcb, RevC.sch]
2016-01-19 fixed hang on no arguments
    [main.cpp]
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2016-07-08 fixed incorrect ip address for shscheduler
    [main.cpp]
2016-07-10 moved energy sensor to nice case and various tweaks
    [EnergySensor.kicad_pcb, EnergySensor.sch]
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2016-07-10 moved text and created exports for energy sensor
    [EnergySensor.kicad_pcb]
2016-07-10 created and exported KiCAD version of nrf24l01 sensor
    [NRF24L01.kicad_pcb, NRF24L01.sch]
2016-08-05 fixed missing wire
    [NRF24L01.kicad_pcb]
2016-08-05 changed cpu clock and set adc to correct clock speed
    [EnergySensor.cpp]
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2016-08-27 fixed typo, and removed excess variable
    [main.cpp]
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
